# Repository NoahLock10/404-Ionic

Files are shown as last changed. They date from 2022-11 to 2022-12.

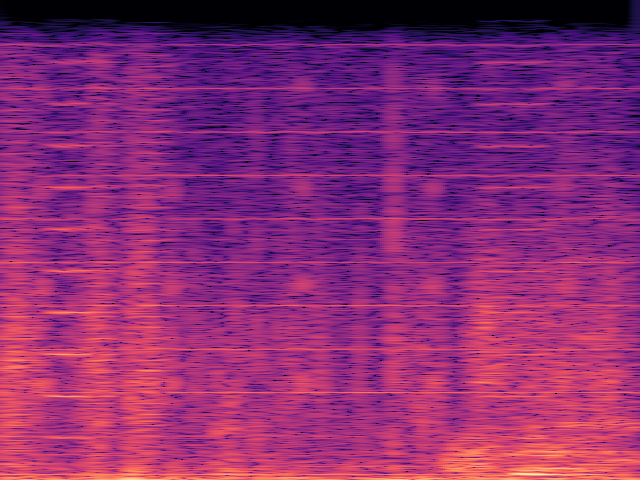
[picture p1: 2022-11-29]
AI_and_Wearable/Pipeline/Scripts/melspec_files/TEST.png

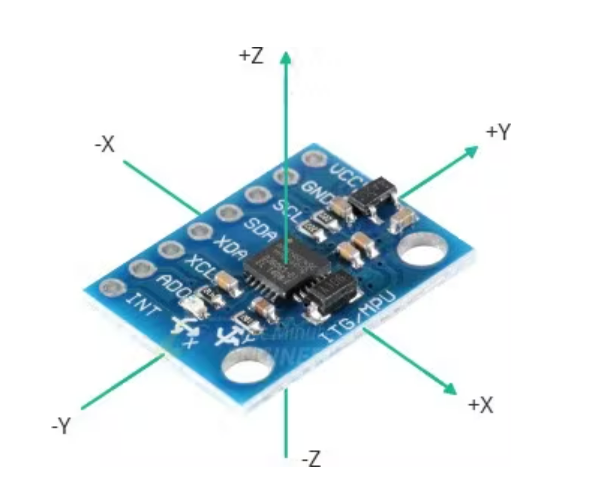
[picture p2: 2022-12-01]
Micro Controller Subsystem/accelrometer axis.png

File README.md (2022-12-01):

# Meltdown_Team-12_Fall_2022

The "src" folder holds the code Noah Lockhart wrote to create the app and connect to the database.
The "android" folder holds the code to allow the app to run on android phones.

The "AI and Wearable" folder holds the code Jason and Josh worked on to record the data on the wearable, 
send the data to the database, and make a meltdown prediction using the AI.

Within the "AI and Wearable" folder, the "Sensors" folder has two subdirectories.
"AI and Wearable/Sensors/Scripts" has all the python scripts used for data collection, as well as the shell script which runs them all together.
"AI and Wearable/Sensors/Data" has all the .txt files that are populated via the data collection scripts.

Within the "AI and Wearable" folder, the "AI" folder contains the model weights for the acoustic CNN and the biometric ANN.

Within the "AI and Wearable" folder, the "Database" folder contains the python script to upload data to the DB via the API.

Within the "AI and Wearable" folder, the "Pipeline" folder contains python modules which provide preprocessing functions and inference functions.
Additionally, this folder contains a main.py file which extracts all data collected during data collection, preprocesses it, and makes a prediction.

Within the "AI and Wearable" folder, the "Final" folder contains the shell script which first calls our data collection script, and then calls
the pipeline script. 

All of the presentations and documents created during 403/404 (CONOPS, FSR, ICD, etc.) can be found in the root directory of the GitHub.
All of the solidwords and altium files and validation files can be found in the root directory of the GitHub.

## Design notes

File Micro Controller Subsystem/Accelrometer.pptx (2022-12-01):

## MPU6050

- Code Flow Chart

Cron-Job
Automated process that runs all scripts on Raspberry Pi 4

Initial Accelerometer Conditions
Setting registers and importing modules

Read_byte(reg)
Reading the address

Read_word(reg)
Reading accelerometer values off MPU6050

Bus Interface
How communication between Pi and MPU6050 is achieved

Data Collection
How Data is collected

Final Output

smbus2
Combine I2C read and write transactions

Return bus.read_byte_data(address, reg)
This is to read a register 0x68 to the circuit

H = bus.read_byte_data(address, reg)
The MPU6060 provides sensor data as unsigned short 16 bit values (-32768 to +32767

Bus = smbus2.SMBus(1)
Interface communication with I2C bus

F = open(“Data/accel.txt”, “w”)
Packet data into txt file

Accel.txt
The final txt file with x, y, and z accelerations

Math/Time
Used for calculations and delays

Address
Lists the addresses of the registers to read a value and the addresses available

L = bus.read_byte_data(address, reg+1)
This data is split across 2 8 bit registers (0-255)

Bus.write_byte_data(address, reg_1, 0)
Write register to the circuit in this case it is a 0

Acceleration_xout = read_word_2c(0x3b)
Utilizes for loops to collet scaled acceleration values from registers

Reg_1 and Reg_2
MPU6050 power management registers (The lists of registers and their address is available in the circuit specification)

Value = read_word(reg)
Reads pair of 8 bit registers

f.write
Writing Data to txt file

If (val>=0x8000)
Converts results to a 16 bit value

## CONTOSO

- Organization chart

Kalle Persson
HR Manager

Flora Berggren
VP Human Resources

April Hansson
Marketing Manager

Mira Karlsson
VP Marketing

Victoria Hanssen
HR Manager

Kalle Persson
Marketing Manager

Angelica Hansson
Product Manager

Mirjam Nilsson
President

Angelica Astrom
Engineering Director

Allan Mattsson
VP Technology

Kalle Persson
VP Product

Victoria Hansson
Product Manager

Jens Martensson
Product Manager

August Bergqvist
VP Finance

Ian Hansson
Accounting Manager

Victoria Persson
VP Transportation

Alexander Martensson
Accounting Manager

## CONTOSO

- Organization chart

Mirjam Nilsson
President

August Bergqvist
VP Finance

Kalle Persson
Accounting Manager

Allan Mattsson
VP Technology

Kalle Persson
Engineering Director

Flora Berggren
VP Operations

Kalle Persson
Facilities Manager

Mira Karlsson
VP Marketing

Kalle Persson
Marketing Manager

Kalle Persson
VP Product

Kalle Persson
Product Manager

Victoria Persson
VP Human Resources

Kalle Persson
HR Manager

Kalle Persson
Accounting Manager

Kalle Persson
Marketing Manager

Kalle Persson
Product Manager

Kalle Persson
HR Manager

Kalle Persson
Accounting Manager

Kalle Persson
HR Manager

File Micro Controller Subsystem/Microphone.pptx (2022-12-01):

## Recorder.py

- Overview of microphone code

Cron-Job
Automated process that runs all scripts on Raspberry Pi 4

Initial Microphone Configurations

Pyaudio.PyAudio()

For loop
Adding chunks of audio to frame array

Stream
Stopping the data collection

Wavfiles
Creating wavfile from recorded audio with microphone requirments

Environment.wav
Final output file

Form_1 = pyaudio.paInt16
Initializing a 16-bit resolution

Audio = pyaudio.PyAudio()
Creating an instantiation of pyaudio

Frames.append(data)
Adding the parsed data to new frame array

Stream.stop
Stop stream

Wave.open
Open create and write

Verification
Matlab code in appendix A verifies data using spectrograph

Chans =1
1 channel being created

Stream = audio.open()
Creating a stream that can later be parsed

Samp_rate/chunk *record_secs
How many iterations of collection

Stream.close
Close the stream

Wave.setnchannels
Only create 1 channel

samp_rate = 44100
Chunk = 4096
Collecting audio at 44.1 kHz with 4096 samples

Print(“recording”)
Visible proof that there is audio being recorded

Audio.terminate
Stop recording

Wave.setsamplewidth
Set wavfile sample rate to 44100 HZ

Record_specs = 3
dev_index = 2
Recording audio for 3 seconds and setting which USB port is being used

Format of audio.open
Default settings for microusb microphone

Wavefile.writeframes
Combining all created frames

## CONTOSO

- Organization chart

Kalle Persson
HR Manager

Flora Berggren
VP Human Resources

April Hansson
Marketing Manager

Mira Karlsson
VP Marketing

Victoria Hanssen
HR Manager

Kalle Persson
Marketing Manager

Angelica Hansson
Product Manager

Mirjam Nilsson
President

Angelica Astrom
Engineering Director

Allan Mattsson
VP Technology

Kalle Persson
VP Product

Victoria Hansson
Product Manager

Jens Martensson
Product Manager

August Bergqvist
VP Finance

Ian Hansson
Accounting Manager

Victoria Persson
VP Transportation

Alexander Martensson
Accounting Manager

## CONTOSO

- Organization chart

Mirjam Nilsson
President

August Bergqvist
VP Finance

Kalle Persson
Accounting Manager

Allan Mattsson
VP Technology

Kalle Persson
Engineering Director

Flora Berggren
VP Operations

Kalle Persson
Facilities Manager

Mira Karlsson
VP Marketing

Kalle Persson
Marketing Manager

Kalle Persson
VP Product

Kalle Persson
Product Manager

Victoria Persson
VP Human Resources

Kalle Persson
HR Manager

Kalle Persson
Accounting Manager

Kalle Persson
Marketing Manager

Kalle Persson
Product Manager

Kalle Persson
HR Manager

Kalle Persson
Accounting Manager

Kalle Persson
HR Manager

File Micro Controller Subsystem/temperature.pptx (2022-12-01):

## Temperature Sensor

- Code Flow Chart

Cron-Job
Automated process that runs all scripts on Raspberry Pi 4

Initial Imports
Import modules necessary for data collection

Def read_temp_raw()
Reading data into file with non converted data

Def read_temp()
Stripping the data so each individual value can be converted to Fahrenheit through a while loop

Conversion
Raw data to Fahrenheit

Data Collection
10 values produced in 30 seconds

Final Output

Import os
Used to read from Pi and temperature sensor

Device_folder = glob.glob(base_dir +’28’)
Default location of sensor in PI

While lines[0].string()[-3:]
While loop checking if there's data

Temp_f = temp_c * 9 /5 +32
Numerical conversion

f.write(curr_temp +’\n’)
Writing new data to final output

Temp.txt
When final temperature values go

Import glob
Finds all pathnames matching a specified pattern

Device_file = device_folder + ‘/w1_slave’
Default location of sensor data in pi

Lines = read_temp_raw()
Getting values using loops

Import glob
Finds all pathnames matching a specified pattern

Lines = f.readlines()
Reading file data line by line

Return lines
Returning the data so future functions can use it

## CONTOSO

- Organization chart

Kalle Persson
HR Manager

Flora Berggren
VP Human Resources

April Hansson
Marketing Manager

Mira Karlsson
VP Marketing

Victoria Hanssen
HR Manager

Kalle Persson
Marketing Manager

Angelica Hansson
Product Manager

Mirjam Nilsson
President

Angelica Astrom
Engineering Director

Allan Mattsson
VP Technology

Kalle Persson
VP Product

Victoria Hansson
Product Manager

Jens Martensson
Product Manager

August Bergqvist
VP Finance

Ian Hansson
Accounting Manager

Victoria Persson
VP Transportation

Alexander Martensson
Accounting Manager

## CONTOSO

- Organization chart

Mirjam Nilsson
President

August Bergqvist
VP Finance

Kalle Persson
Accounting Manager

Allan Mattsson
VP Technology

Kalle Persson
Engineering Director

Flora Berggren
VP Operations

Kalle Persson
Facilities Manager

Mira Karlsson
VP Marketing

Kalle Persson
Marketing Manager

Kalle Persson
VP Product

Kalle Persson
Product Manager

Victoria Persson
VP Human Resources

Kalle Persson
HR Manager

Kalle Persson
Accounting Manager

Kalle Persson
Marketing Manager

Kalle Persson
Product Manager

Kalle Persson
HR Manager

Kalle Persson
Accounting Manager

Kalle Persson
HR Manager

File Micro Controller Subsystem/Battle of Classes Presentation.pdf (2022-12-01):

Gavin Marquez: (Leader) Hardware and Sensors Lead

Alexander Duvall: (Assistant Leader) Software and Firmware Lead

Allen Torres: (Resource Manager) System and Automation Lead

Joel Martinez: (Scribe) Communication and Networking Protocol Lead

Saif Momin: (Reflector) Modeling and Prototyping Lead

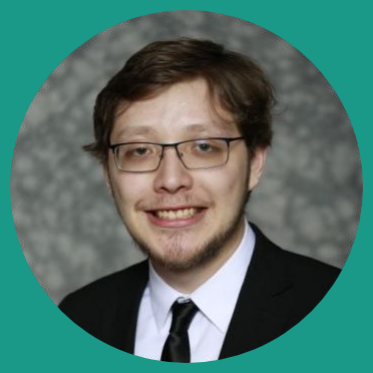
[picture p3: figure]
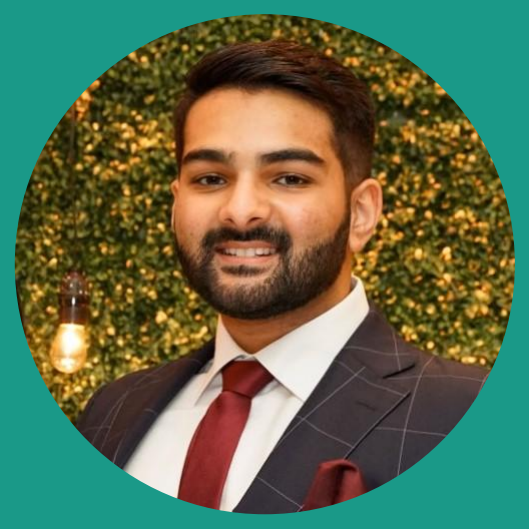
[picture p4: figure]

# Project MARKUS: Ai Driven Solutions

# What is ASD?

Autism Spectrum Disorder, a developmental disability that causes serious social, behavioral and communication challenges.

- Diagnosis for Autism Spectrum Disorder (ASD) encompasses:
- Autistic Disorder; Pervasive Developmental Disorder (PDD-NOS); Asperger Syndrome
- Signs and Symptoms:
- Social, Emotional, and Communication problems
- Behavioral Therapy used to treat ASD
- Helps in cognitive and social development.
- Helps develop daily living skills
- Assists individuals communicating with the Community
- Each individual is different and requires different forms of therapy
- Behavioral therapy is commonly used with children
- Not many people treat ASD in adults or teens.

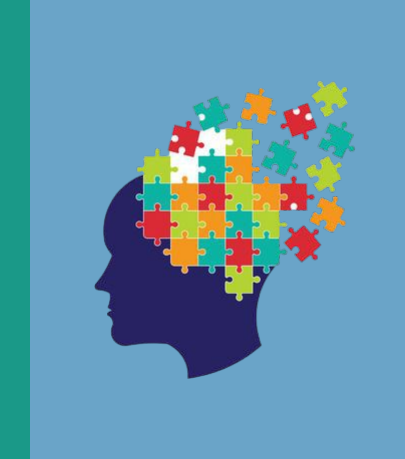
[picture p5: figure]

“Findings estimate autism affects 1 in 45, or 2.21 percent, of U.S. adults.” - AutismSpeaks | [1,2,5]

# Common Occurrences with ASD

Each person with ASD is different, but through
interviews, we have been able to narrow down some common trends through interviews and research:
- Sensory Overloads
- Sounds, loud or high pitched.
- Fluorescent lights
- Such sensations can be painful
- Strong smells as triggers
- Discomfort in clothing
- Loss in routines may cause problems
- Lack of micro-expressions
- Indicator of someone on the spectrum

Upon a disturbing noise, an individual with ASD may cover their ears to limit pain.

Information gathered in conjunction with Jennifer Morgan, Sofia Lumbo, and Marianne [1,2,6]

# What are meltdowns?

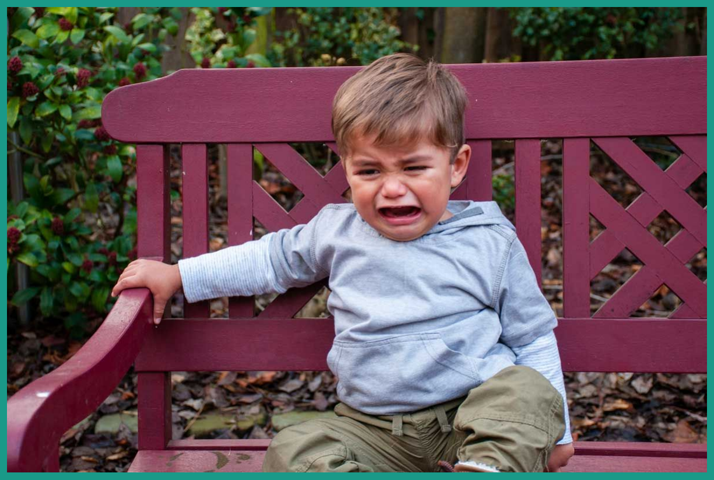
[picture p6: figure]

- Meltdowns : is an intense response to overwhelming circumstances—a complete loss of behavioral control.
- Causes of Meltdown: Sensory Overload, Information Overload, Emotional Overload
- Examples: Physical Sign of Anxiety, Need to leave the environment, or physical harm towards oneself

Information gathered in conjunction with Jennifer Morgan, Sofia Lumbo, and Marianne [3,4]

## What can we do?

- Preventive Measure for Meltdown.
- Deescalate the situation
- Interruption and Transitions
- Practice Routine and practice change in routine
- Provide Safe Space
- Redirect their attention elsewhere.
- Early Intervention is key to saving lives

# What are meltdowns?

# Meet Markus

Markus is a Wearable device that will watch and monitor the wearer and their environment.

- Artificial Intelligence
- Monitor for Noise, stimuli
- Microphone
- Stress levels
- Heart Rate
- Location
- Temperature
- Environmental Attributes
- Camera

While the belt is on, Markus will be able to utilize Ai to ensure the user is well.
With this technology, Markus will be able to prevent or deescalate meltdowns, help find a missing person, and speak to them. Information gathered in conjunction with Jennifer Morgan,Sofia Lumbo and Marianne

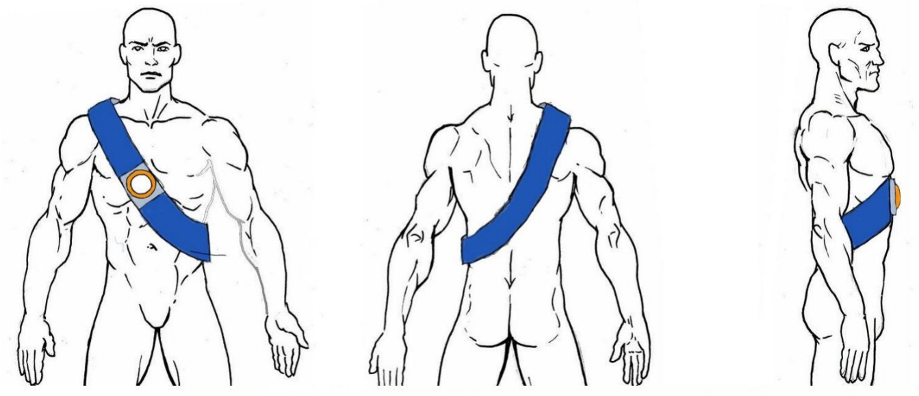
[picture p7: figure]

While the belt is on, Markus will be able to utilize Ai to ensure the user is well.
With this technology, Markus will be able to prevent or deescalate meltdowns, help find a missing person, and speak to them. Information gathered in conjunction with Jennifer Morgan,Sofia Lumbo and Marianne

# Markus AI Model

The brain of Markus will be using a custom built deep learning model. The Ai will be able to understand environmental sounds and determine if a meltdown is imminent with information from other sensors.

### Training

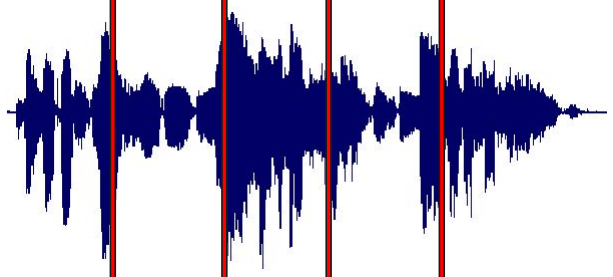
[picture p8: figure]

Audio Samples were recorded from a variety of environments like:
- Malls
- Retail stores
- Restaurants
- Festivals
- Public Areas

Audio Samples were then split up to 1.5 seconds each and used for training.

Every 1.5 seconds, Markus interprets the environment’s sounds into 6 categories
- Quiet, Small Conversation, Large conversation, Stimuli Wind, noise

# Markus Artificial Intelligence

# Markus Artificial Intelligence

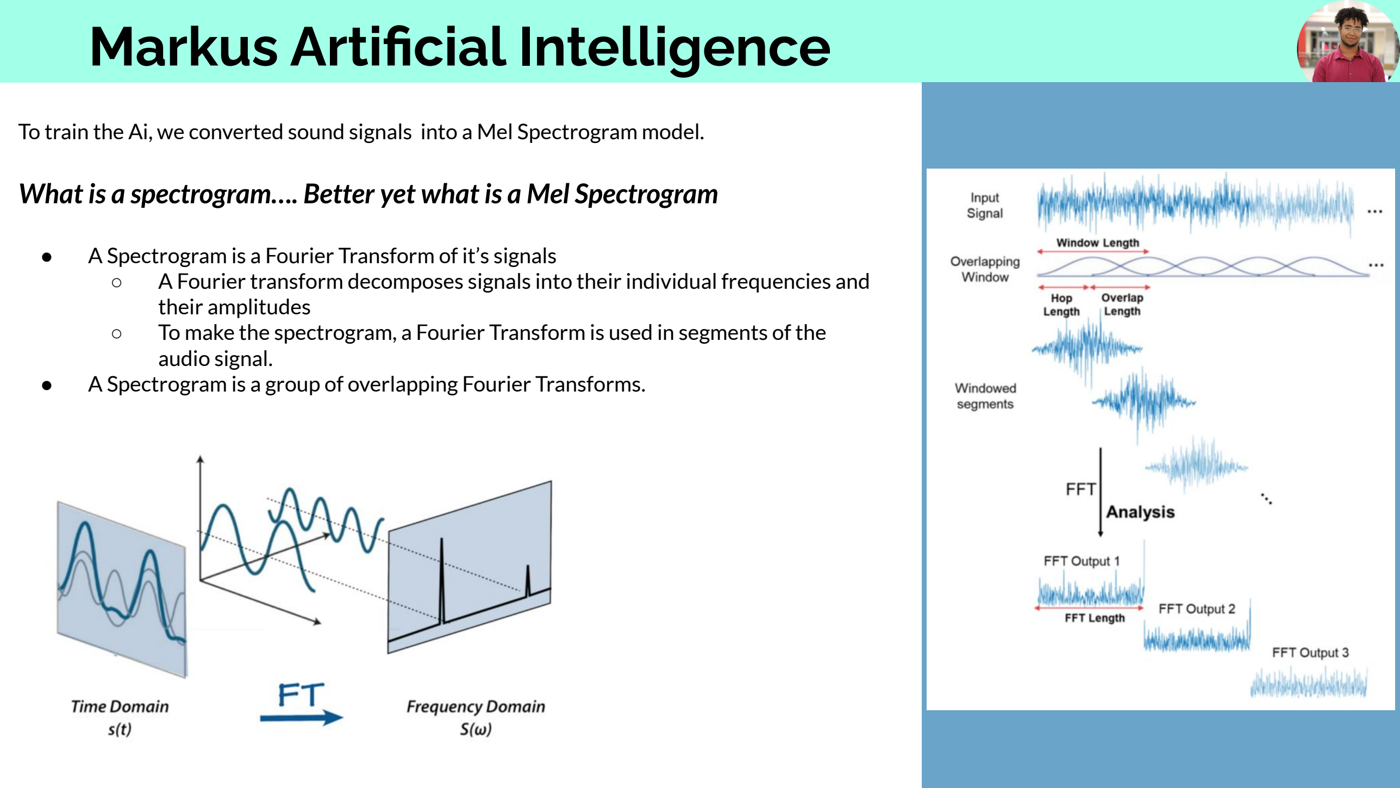
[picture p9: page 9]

To train the Ai, we converted sound signals into a Mel Spectrogram model.

What is a spectrogram…. Better yet what is a Mel Spectrogram

- A Spectrogram is a Fourier Transform of it’s signals
- A Fourier transform decomposes signals into their individual frequencies and their amplitudes
- To make the spectrogram, a Fourier Transform is used in segments of the audio signal.
- A Spectrogram is a group of overlapping Fourier Transforms.

# Markus Artificial Intelligence

Okay, what about a Mel Spectrogram?

- A Mel Spectrogram is a spectrogram converted to how human’s interpret sound
- Humans can tell the difference between a 500 and 1000 Hz sound
- However, we can not tell the difference between a 10,000 and 15,000 Hz Sound
- Depending on the frequency of the sound, it is given a pitch value that is equivalent to how we interpret sound.
- This interpretation is then calculated into a new spectrogram

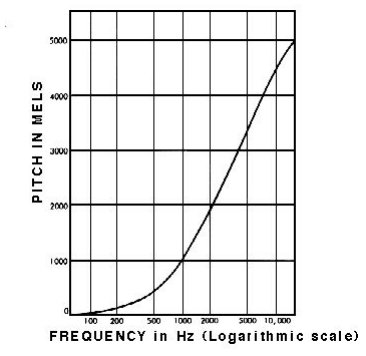
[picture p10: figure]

# Markus Artificial Intelligence

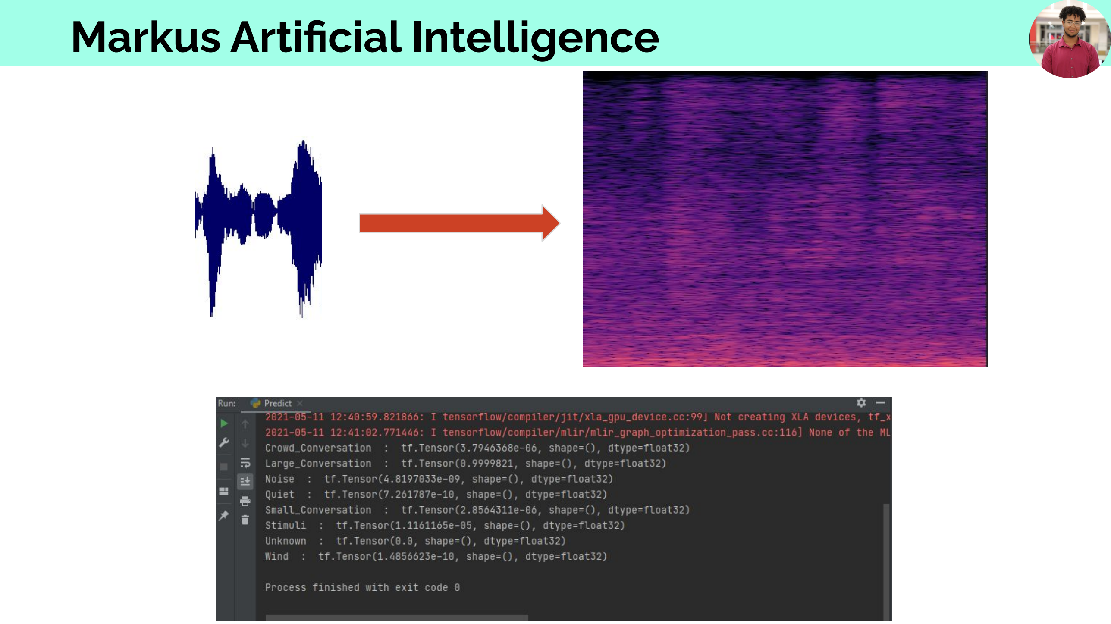
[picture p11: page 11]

# Markus Artificial Intelligence Performance

# Markus Artificial Intelligence Performance

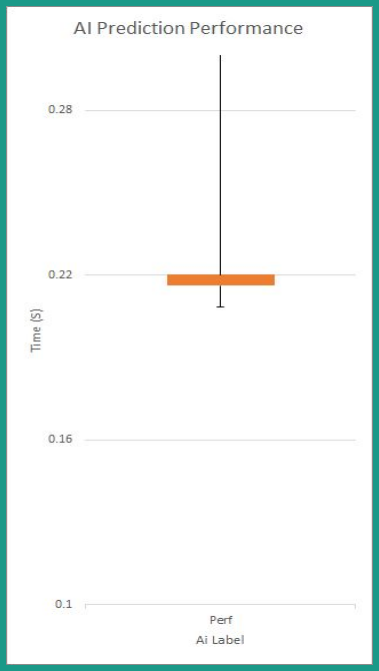
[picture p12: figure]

# GPS Sensor Performance

# Heart Beat Sensor Performance

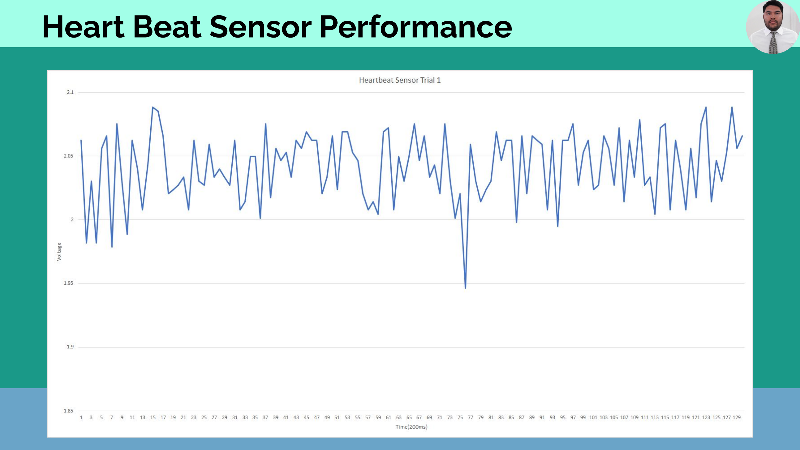
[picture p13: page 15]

# Heart Beat Sensor Performance

# Heart Beat Sensor Performance

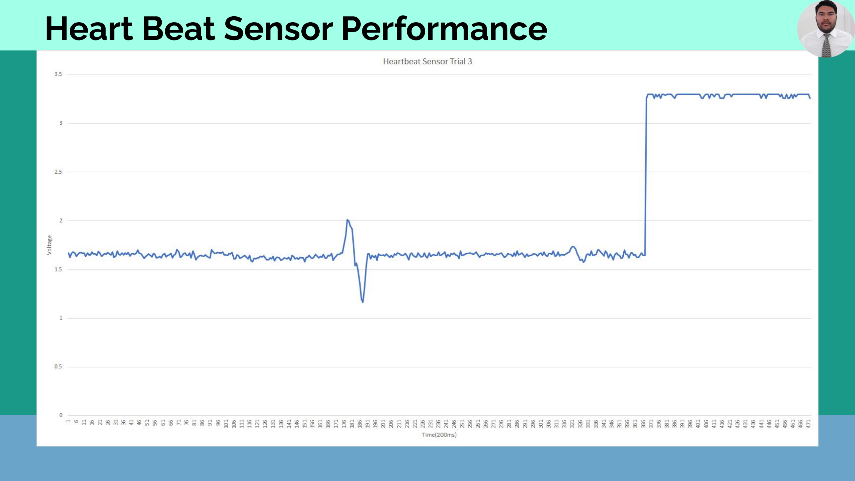
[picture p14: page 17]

# Putting it all together - Servers

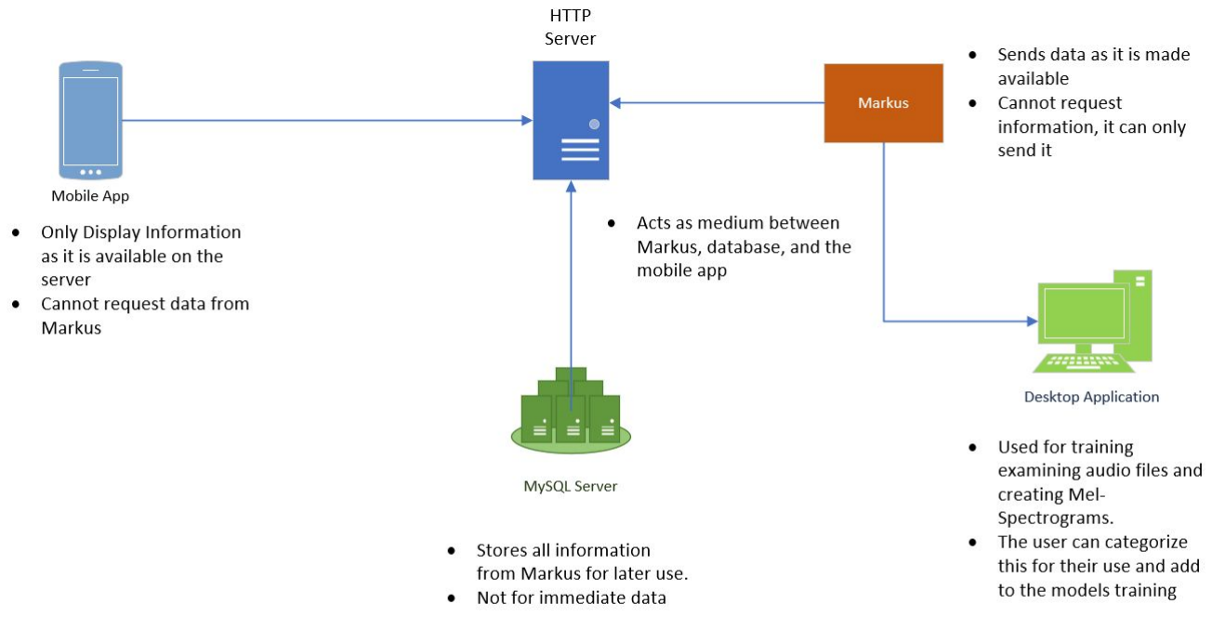
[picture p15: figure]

# Putting it all together - Servers

React Native and Expo.IO

-React Native allows for the Combination of JavaScript, CSS, and HTML all combined into one to create native mobile application for both IOS and Android Devices

-Expo.io an online IDE used to build React Native application and test with in real time. Expo.io allows for the application to be loaded onto a mobile device for live testing as well

# Tools to create the Mobile Application

With the mobile app, a guardian or caretaker can directly monitor their individuals status and environment. Everything Markus can see and hear is sent directly to the phone

- With an Embedded Camera and Microphone Markus can live
stream video and calls.
- Markus’ location, pressure, altitude, and humidity are directly sent
to the app.
- The ai’s interpretation of the environment is also sent to the app.

All information is updated as it is made available

# Mobile Application

# Mobile Application (2)

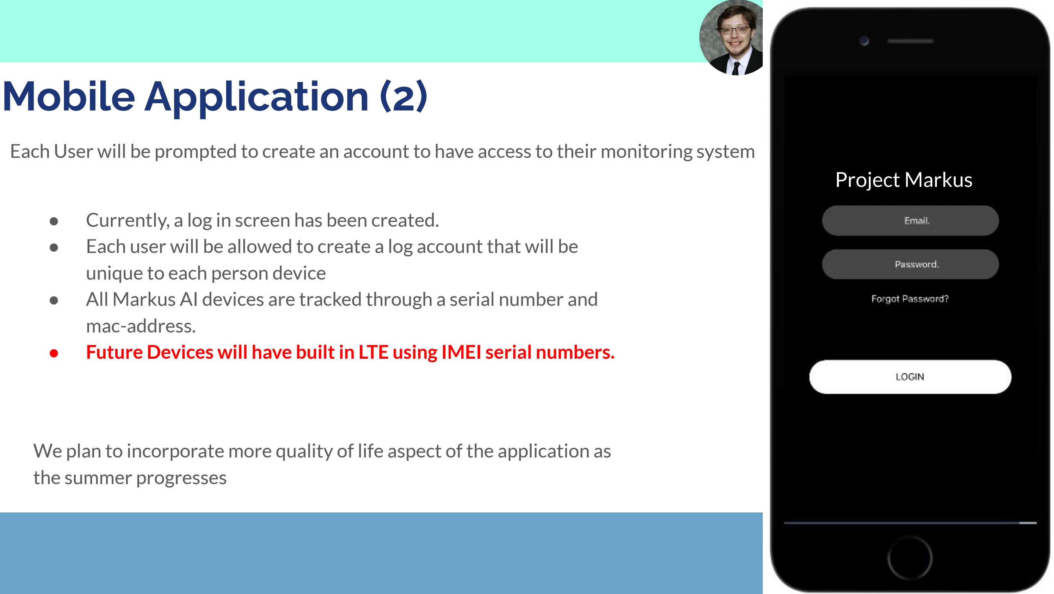
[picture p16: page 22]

Each User will be prompted to create an account to have access to their monitoring system

- Currently, a log in screen has been created.
- Each user will be allowed to create a log account that will be
unique to each person device
- All Markus AI devices are tracked through a serial number and mac-address.
- Future Devices will have built in LTE using IMEI serial numbers.

We plan to incorporate more quality of life aspect of the application as the summer progresses

Project Markus

# NVIDIA Jetson Nano - The Brain

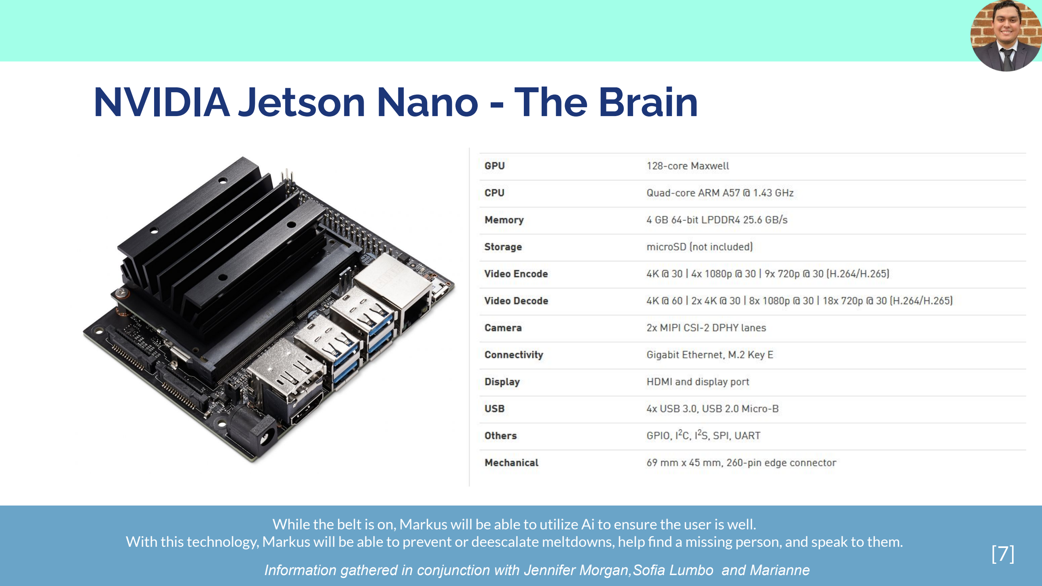
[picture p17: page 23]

While the belt is on, Markus will be able to utilize Ai to ensure the user is well.
With this technology, Markus will be able to prevent or deescalate meltdowns, help find a missing person, and speak to them.

Information gathered in conjunction with Jennifer Morgan,Sofia Lumbo and Marianne

Nvidia’s Jetson Nano is an embedded system that allows multiple neural networks to run in parallel. These neural networks can be used for:

- Image Classification
- Object Detection
- Segmentation
- Speech Processing

This device runs on 5 watts, and it is able to train and deploy AI software.

[7]

BME280: Environmental sensor that measures Temperature, Humidity, Pressure, and Altitude

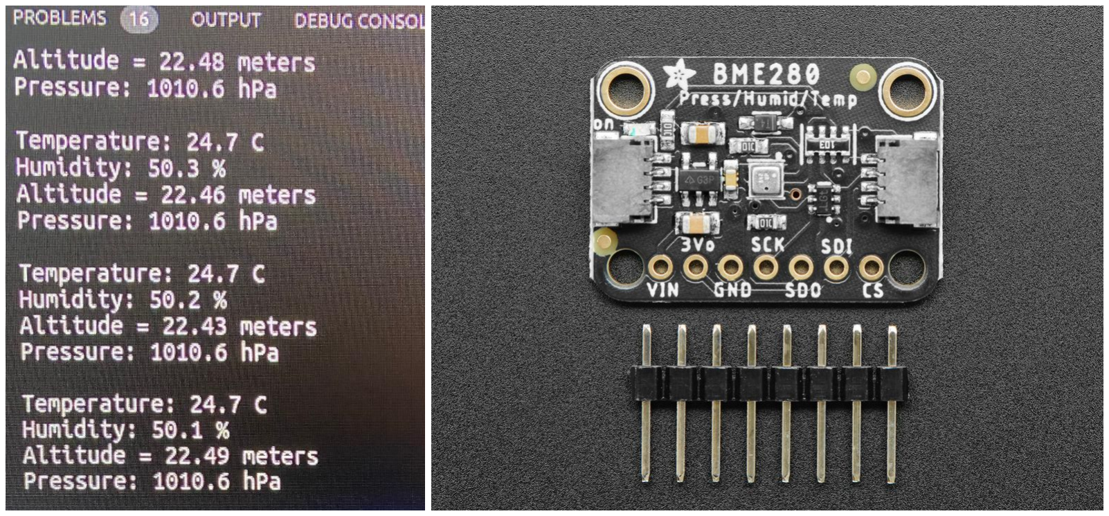
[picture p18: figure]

- Can be wired using I2C or SPI
- Temperature accuracy with ∓ 1.0C
- Humidity accuracy with ∓ 3%
- Pressure accuracy with ∓ 1 Hpa
- Altitude accuracy with ∓ 1 meter ●

# Temperature Sensor

Ultimate GPS Breakout V3: High quality GPS module that can track up to 22 satellites on 66 channels.

- Uses UART terminal
- Uses 3.3 - 5V
- Can connect any 3V active GPS antenna for better accuracy ●

# GPS Sensor

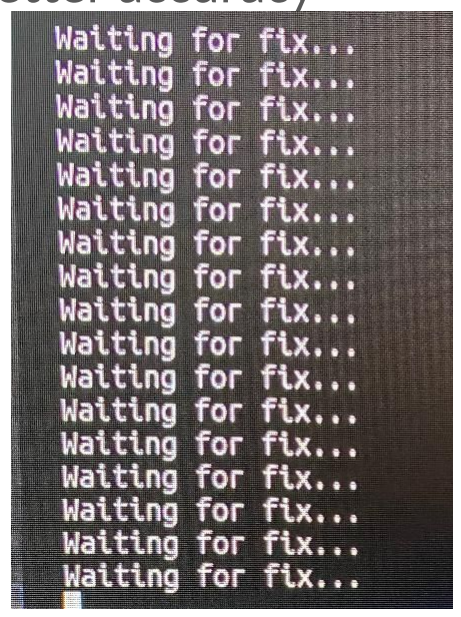
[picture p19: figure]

Pulse Sensor: uses Photoplethysmography (PPG) to determine heart rate. PPG accuracy are heavily affected by measurement procedure and environmental factors.

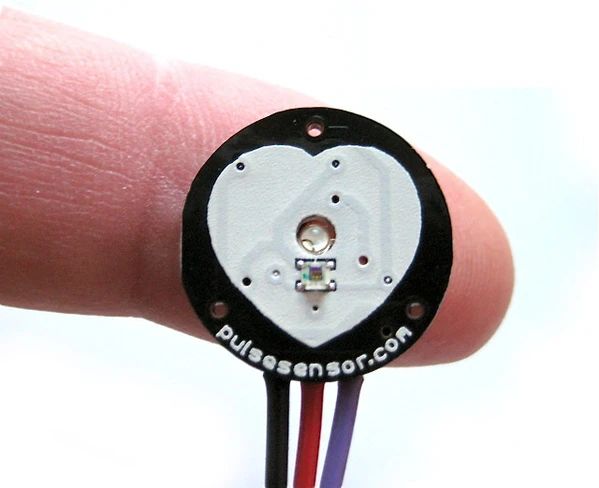
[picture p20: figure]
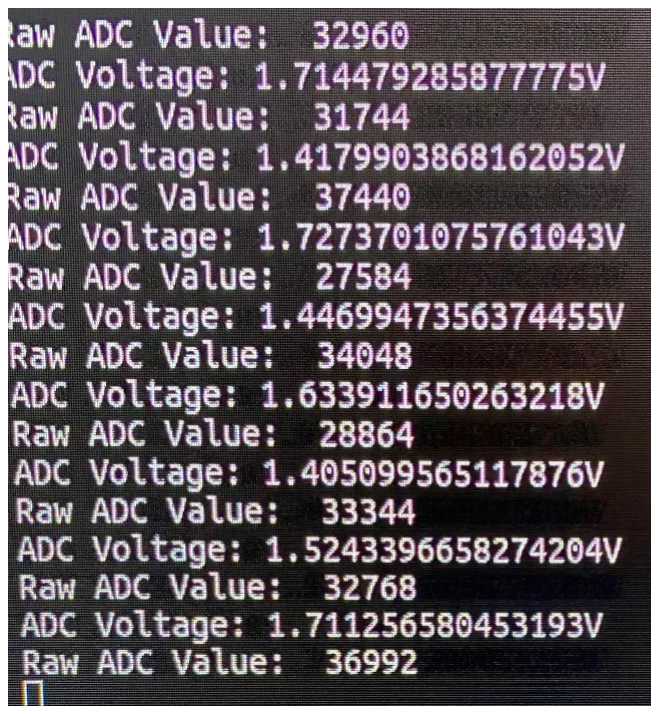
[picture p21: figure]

- Analog Signal
- Uses 3 - 5V
- Can be worn around finger, or earlobe

# Heart Rate Sensor

Raspberry Pi Module V2:

- Small Compact Size
- Resolution up to 1080p at 30 fps
- Still resolution of 8 Megapixels
- Horizontal Field of View of 62 degrees

# Camera

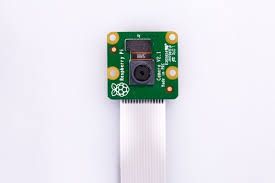
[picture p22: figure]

# Microphone and Speaker

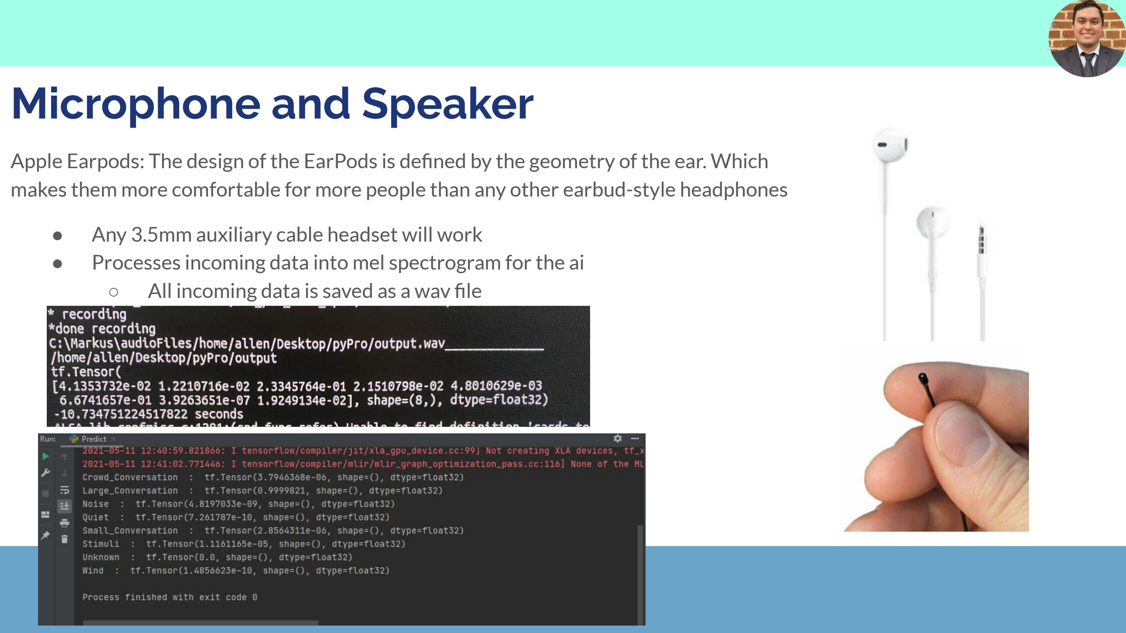
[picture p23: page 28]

Apple Earpods: The design of the EarPods is defined by the geometry of the ear. Which makes them more comfortable for more people than any other earbud-style headphones

- Any 3.5mm auxiliary cable headset will work
- Processes incoming data into mel spectrogram for the ai
- All incoming data is saved as a wav file

# Demo

3D Model of MARKUS Enclosure

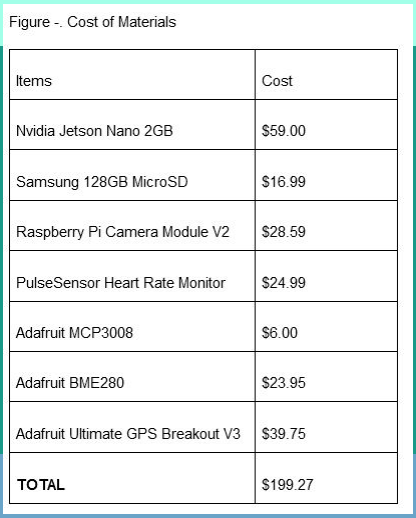
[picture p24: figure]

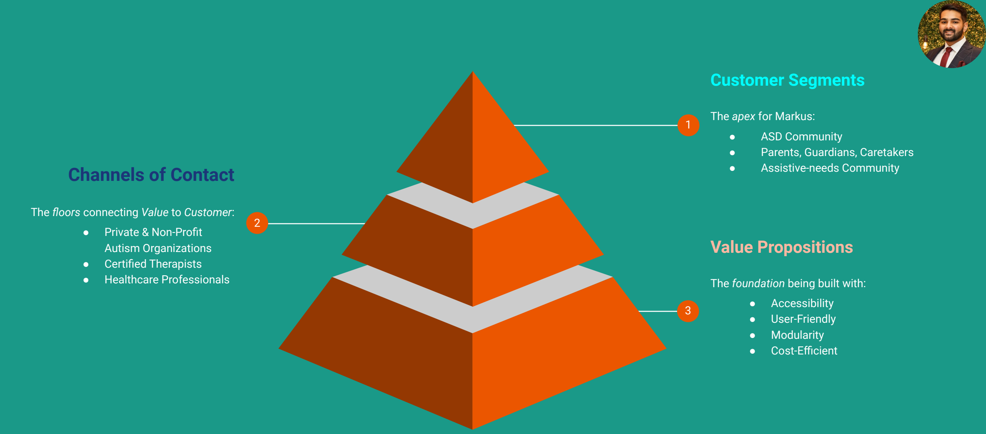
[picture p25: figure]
Value Propositions; The foundation being built with:; ● Accessibility ● User-Friendly ● Modularity ● Cost-Efficient; Channels of Contact; ● Private & Non-Profit Autism Organizations ● Certified Therapists ● Healthcare Professionals; Customer Segments; The apex for Markus:; ● ASD Community ● Parents, Guardians, Caretakers ● Assistive-needs Community

The floors connecting Value to Customer:

# MARKUS: It’s Business

# So what… Why should we care?

Markus is meant to replace human interaction when it is not possible for someone to be there.

### - Preventing meltdowns from occurring - Assisting in the de-escalation of meltdowns - Finding lost individuals that wonder from supervised areas (AKA wondering)

- Learning when a meltdown is going to take place for each individual.

### - Introduce new and familiar grounding exercises

- Early Stage Intervention, when no one is there to intervene.

We hope Markus will become a common assistant that can help those with ASD cope with unpredictable situations and a thing called life.

# Project Shortcomings and Problems

- Mel Spectrogram performance is slow.
- Ai may be biased.
- Server is unable to stream microphone and camera data.
- Pulse Sensor cannot be fit correctly for accurate data
- No Data exists in relation to autism and meltdowns.

# What’s Next?

Work to finetune our proof of concept and prototyping.
Working with Treatment centers all over the US and around the world to research, gather info, and improve Markus AI on ASD individuals.
We will build an online presence using our social media platforms such as:
1. Facebook (Groups such as family with ASD, posting and advertising, Instagram videos/posts)
2. Google (SEO, Youtube Videos)
3. Twitter (Videos)
4. Feature our products on Forbes/Tech Magazines/Startups/etc
5. Crowd Funding: Startups/Indiegogo/etc
6. Website presence and product info
7. Forums: Participate in forums and discussions website Fundings (could be in any order):
Venture capitalists
Angel investors
Crowdfunding
Equity crowdfunding
Incubators
Grants
Friends and Family

The Bauer College of Business’s Red Labs has selected us to continue with our project. This is a great opportunity for us because it will allow us to:

- Gather necessary knowledge in order to create start up
- Network with professionals.
- Keep developing our device.
- Present prototype to industry professionals and companies.

The opportunity offered by Red Labs is a big step into one day making our device available to people with special needs.

# UH Red Labs

# References

[1] What is Autism Spectrum Disorder?, 25-Mar-2020. [Online]. Available: https://www.cdc.gov/ncbddd/autism/facts.html. [Accessed: 19-Nov-2020].
[2] “CDC estimates 2.2 percent of adults in U.S. have autism,” Autism Speaks, 13-May-2020. [Online]. Available: https://www.autismspeaks.org/science-news/cdc-estimates-22-percent-adults-us-have-autism. [Accessed: 19-Nov-2020].
[3] “Meltdown,” Merriam-Webster. [Online]. Available: https://www.merriam-webster.com/dictionary/meltdown. [Accessed: 19-Nov-2020].
[4] “Keeping Your Child with Autism Safe,” The Autism Community in Action (TACA), 19-Oct-2020. [Online]. Available: https://tacanow.org/family-resources/keeping-your-kids-with-asd-safe/. [Accessed: 19-Nov-2020].
[5]Centers for Disease Control and Prevention. 2020. Treatment | Autism Spectrum Disorder (ASD) | NCBDDD | CDC. [online]
Available at: <https://www.cdc.gov/ncbddd/autism/treatment.html> [Accessed 30 November 2020].
[6] Healthline. 2020. Sensory Overload: Symptoms, Causes, Related Conditions, And More. [online] Available at: <https://www.healthline.com/health/sensory-overload#causes> [Accessed 30 November 2020].
[7]“Jetson Nano Developer Kit,” NVIDIA Developer, 09-Oct-2020. [Online]. Available: https://developer.nvidia.com/embedded/jetson-nano-developer-kit. [Accessed: 15-Dec-2020].

Gavin Marquez: (Leader) Hardware and Sensors Lead

Alexander Duvall: (Assistant Leader) Software and Firmware Lead

Allen Torres: (Resource Manager) System and Automation Lead

Joel Martinez: (Scribe) Communication and Networking Protocol Lead

Saif Momin: (Reflector) Modeling and Prototyping Lead

# Supplementary Slides

# THANK

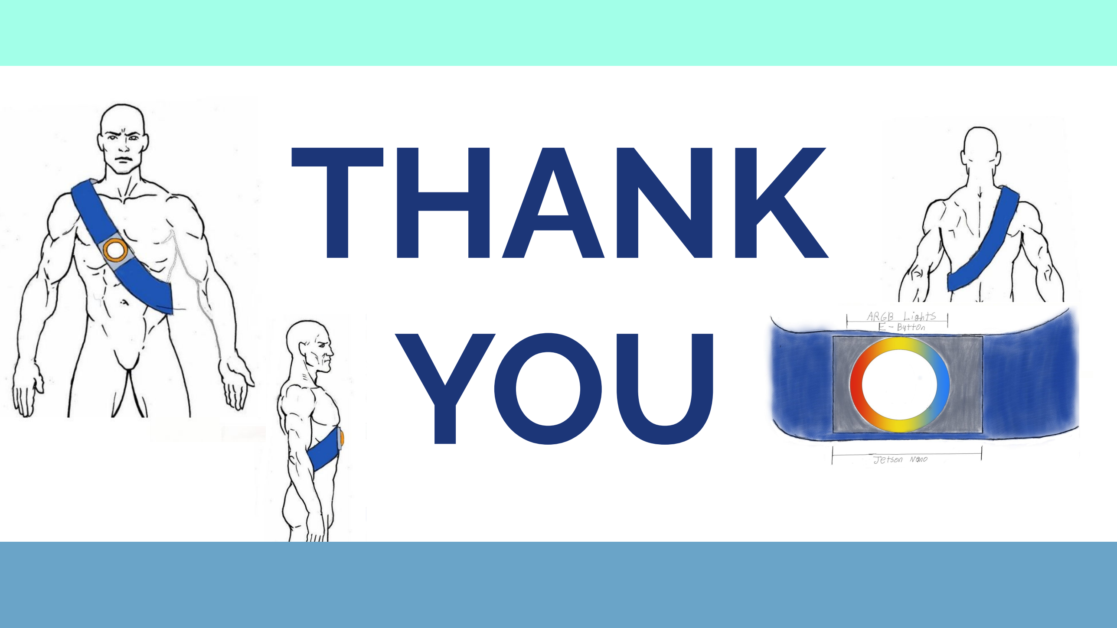
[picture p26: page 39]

# YOU

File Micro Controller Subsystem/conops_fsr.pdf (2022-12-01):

# Mitigating Autistic Meltdowns

## Joshua Kao, Jason Kroslowitz, Noah Lockhart, Andres Perez

# Concept of Operations

### REVISION – Draft

### 06 February 2022

Concept Of Operations | Revision 1
Mitigating Autistic Meltdowns

## Concept of Operations

## for

# Mitigating Autism Meltdowns

Team 12

Approved by:

__Team 12___________________2/08/22__

Project Leader | Date

___________________________________

Prof. Kalafatis | Date

___________________________________

T/A | Date

### Change Record

Rev. | Date | Originator | Approvals | Description
-1 | [2/08/2022] | [Team 12] | | Draft Release

### Table of Contents

### List of Figures

# 1. Executive Summary

An autistic meltdown is an involuntary coping mechanism to excessive stimuli, and can be associated with intense and explosive behaviors. These events pose a threat to the safety of these individuals and in some cases others around them. Rather than having a caretaker supervise them 24/7, we propose a device that mitigates meltdowns for these individuals. The 12th Man is a hip wearable device that mitigates meltdowns for individuals with Autism. By monitoring the user's biometrics, the 12th Man uses artificial intelligence to process these signals and predict if a meltdown is imminent. If a meltdown is imminent, an alert is sent to the subject's parent(s) or guardian through an app with the location of the individual and the probability that a meltdown is going to happen. On the device itself a recording from a loved one is played with grounding exercises to calm down the individual. We are hoping that through this device, the lifestyles of autistic people can be changed.

# 2. Introduction

The following is an introduction to The 12th Man, a device capable of monitoring, mitigating, and supporting individuals with autism no matter where they are. The 12th Man will provide a sense of comfort for these individuals and their loved ones through its prediction, mitigations, and location tracking of meltdowns.

## 2.1. Background

Autism spectrum disorder (or ASD for short) is a disorder that affects social, emotional, and communication skills. Although the cause is still unknown, it is believed to develop from a combination of genetic, nongenetic, and environmental influences. Recently, ASD has been more heavily researched, and as a result, more conditions have been connected to the disorder. Although symptoms differ per individual, some common symptoms include anxiety, ADHD, epilepsy, schizophrenia, and others.

It is also common for individuals with ASD to be easily agitated. Due to this, meltdowns are an ailment that affect many autstic people. A meltdown is a result of stressors that cause an overload for the individual. During a meltdown, “involuntary physical and emotional reaction to a situation” can occur. While meltdowns can happen with any individual, people with ASD are more prone to them due to the inability to process the overload of stimulants from the surrounding environment. Some examples of these extraneous stressors could be any variety of loud noises, large crowds, and sometimes just everyday life. Meltdowns can result in devastating effects such as wandering, self harm, harm to others, and in the worst case scenarios death.

Typically when addressing meltdowns, it is best to try to prevent them from even happening. Family and friends are the best suited for this task since these individuals understand when there could be potential stressors to the person expecting a meltdown. They are also the most equipped to develop grounding exercises which can help calm the person down. Grounding exercises are a series of activities, patterns, or words that help calm an autistic person down. The tell tale signs are different for each person who experiences a meltdown, so it is important to tailor an individual grounding plan for each person. Currently the method of preventing a meltdown is having the parent/guardian around to assist with the grounding exercises. The other current option is to leave the individual unsupervised.

While having family and friend supervision is ideal, we all know that it is not feasible 24/7. This is where the 12th Man comes to action to predict, prevent, and calm-down meltdowns through artificial intelligence and biometrics.

## 2.2. Overview

The 12th Man device will be a wearable device on the hip that will collect biometric and environmental data such as position, body temperature, heart rate, acceleration, and environmental audio. The devices inside the wearable include a gps module, sensors, and a microphone to collect data. The microcontroller will be supplied power by a rechargeable battery. Data received from the sensors will be filtered and sent to a cloud to be stored and classified. It will then be stored in a database, and will be readily available for the mobile application to fetch and display. If the artificial intelligence infers a meltdown is likely, the mobile application will receive a notification of a possible meltdown. Furthermore, an audio recording of a loved one will be outputted through a speaker on the wearable to aid in the mitigation process. Grounding exercise instructions will be included in the audio to calm the user. Finally, the location of the individual will be tracked in the case of the individual wandering which could lead to dangerous outcomes.

## 2.3. Referenced Documents and Standards

- G., T., Brandon W. | 8 years old, Warren W. | 17 years old, & Andrew S. | 17 years old.
(n.d.). Autism speaks. Autism Speaks. Retrieved February 8, 2022, from https://www.autismspeaks.org/
- How many people are diagnosed with autism in the U.S. Therapeutic Pathways. (2021, February 27). Retrieved February 8, 2022, from https://www.tpathways.org/faqs/how-many-people-have-autism/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,sp ectrum%20disorder%20%E2%80%93%20over%2075%2C000%2C000%20people.

# 3. Operating Concept

## 3.1. Scope

The 12th Man mitigation system for autistic meltdowns is a wearable device composed of a microcontroller and sensors. The system will monitor the biometrics of the wearer and collect data from the individual’s environment. Using artificial intelligence, we will identify the precursors of a meltdown in individuals with autism, and make a prediction about whether a meltdown is likely to occur. If a meltdown is likely to occur, a recording from a loved one will be played through speakers on the wearable. The wearable will also store the data it collects in a remote database. This database will be accessible by a mobile application, which will provide parents/guardians with information regarding the location and meltdown status of their dependent.

## 3.2. Operational Description and Constraints

The 12th Man is a noninvasive, wearable device that operates without any work from the individual. It is intended to be used by the ASD community and their loved ones. While wearing the device, biometric and environmental data will be collected continuously. The wearer will only interact with The 12th Man if an event occurs. Speakers will begin to play audio of their loved ones walking them through a grounding exercise. While using the app, parents/guardians will be able to receive continuous biometric data, location data, and notifications of an imminent meltdown. In order for The 12th Man to perform properly, all the following criteria must be met.

1. The user is wearing the charged 12th Man device.
2. The user is wearing the heart rate monitor around their chest.
3. Parents/Guardians will have to have The 12th Man app installed on their phone and linked to the device.
4. The device wearer must have cellular or internet connection.
5. Past 5 hours the device will lose power causing the user to be unmonitored.

Additionally The 12th Man is not waterproof or perfect. There is a risk of a damaged sensor sending the wrong biometric data to the app which could potentially cause a fake alert.

## 3.3. System Description


Figure 1: The 12th Man Block Diagram

The 12th Man will be composed of four subsystems. These include artificial intelligence, power supply, mobile application, and interfacing sensors with cleaning data.

Interfacing Sensors: The 12th Man device includes 5 different sensors: GPS, temperature, accelerometer, pulse, and audio. Each sensor will be wired to a Raspberry Pi microcontroller. The sensors will collect and “clean” or filter out the noise from the data through a combination of hardware (filters and op amps) along with some software. The data will then be assembled into packets and sent to the cloud.

Power Supply: The wearable device will have a rechargeable battery in place that will be composed of a battery in a battery holder. The battery will be connected to a battery management system for fuel gauge and a charging port. The batteries will be lithium-ion polymer batteries so they will be able to be recharged. The battery will be recharged by an AC/DC adapter. The rechargeable battery will be connected as an input to a boost converter in order to step up the voltage to meet the required specifications to power the microcontroller as the output of the boost converter will be connected to a stripped end of a usb-c cable that will have the usb-c end supply power to the microcontroller. This amp-hour specification of the battery will help make battery life last.

Artificial Intelligence: The AI subsystem has several parts. A supervised learning algorithm has been developed by our sponsor to do classification on audio samples. Data preprocessing will entail converting audio samples to mel spectrograms. A CNN will then classify the likelihood of the audio sample originating from one of six types of environments (small conversation, stimuli, large conversation, etc). Another classification model will be constructed, taking as inputs some/all of the biometrics and the output of the acoustic classifier. This model is the final step in the pipeline to predict a meltdown. Should the environment be deemed stressful or over-stimulative, and the vitals indicative of physiological stress, the model will predict a meltdown is likely to occur. Lastly, we may consider building an additional artificial intelligence based on a generative adversarial network with the hopes of generating convincing “fake” data for biometrics. This will be done should we have issues collecting enough biometric data to train the meltdown prediction model.

App and Database: The database will receive and store all the information the hardware sends it. This will include the GPS location and other readings from the sensors. The app will then present all of this information to the guardian. The guardian will be able to see the location of the individual wearing the device as well as all other sensor readings. If a meltdown is predicted to occur, an alert will be pushed to the mobile application, informing the parent/guardian of the situation.

## 3.4. Modes of Operations

There is only one mode of operation for the system, which is meltdown mitigation. We are intending to provide end-to-end support for individuals with autism as well as their caregivers. The device will operate the same way at all times. An alert will be generated on the mobile application if the device infers that the user is likely to have a meltdown, and an audio recording will be played on the device.

## 3.5. Users

The 12th Man is marketed to the guardians/care-givers of individuals who are diagnosed with Autism Spectrum Disorder. The 12th Man will be used by the person with Autism with the intent of improving quality of life. The device will be worn on the waist along with a bluetooth chest band to sense the heartbeat. The app will be easy to use with all the essential information displayed on the home page. The guardian/caregiver and the individual diagnosed with ASD will benefit from the 12th Man since the guardian/caregiver will be more informed of their dependent’s status and the user will have more security. User installation will not be complex as instructions will guide the user and guardian/caregiver to utilizing the 12th Man.

## 3.6. Support

The users will receive a manual with instructions on how to equip the 12th Man wearable on the individual. Provided the sensors are able to collect biometric and environmental data properly, we may include alternative options of wearing the device. The user manual will also include battery life information, cleaning instructions, and warnings. Warnings will be provided to maintain the life span of the 12th Man such as mentioning that the device will not be water-proof and would not be ideal in a water-based environment. Furthermore, we will provide instructions on downloading the mobile application and linking it to the 12th Man device for guardian/caregiver use. The user manual will also have instructions on how to interact with the mobile application to view alerts and the corresponding data retrieved from the device. In the future, it may prove beneficial to have a live call center that a person can receive customer support from.

# 4. Scenario(s)

## 4.1. People with Autism

The main usage of the 12th Man is to be worn by people with autism to help them mitigate a meltdown before it occurs. When people with autism are out in public, they can get into situations that can be stressful and overwhelming. When this happens, a meltdown can occur. By monitoring the environment and the biometrics of the wearer, The 12th Man will be able to detect when they are about to have a meltdown. If a meltdown is detected, the device will guide the individual with grounding exercises to calm them down while sending a meltdown alert to the guardian through the mobile application. The guardian will also receive the individual’s location for the case of wandering.

## 4.2. People with Panic Attacks

Another use of the 12th Man could be to detect panic attacks. Since meltdowns can exhibit similar physiological responses as a panic attack does, the device may be used interchangeably. Panic attacks can be caused by an overwhelming amount of stimuli, like crowded areas or loud noises. In addition, panic attacks lead to an increase in heart rate and a shortness of breath. The 12th man can detect when these things are happening and can notify the user of an impending panic attack. The device can also contact a loved one through the app via an alert to let them know that the user is about to or having a panic attack.

## 4.3. Exercise

The 12th man can also be used by people who are exercising or doing physical activities. By tracking the user’s heartbeat and their location, a program can be added to the app to document and show their workout. Additionally, if someone is climbing a mountain, an application can be added to make sure the climber is alright. By tracking the user's heartbeat, the 12th Man can tell the wearer if their heart rate is slowing due to a lack of oxygen.

# 5. Analysis

## 5.1. Summary of Proposed Improvements

- The device will have a heartbeat sensor to detect when the individual’s heartbeat is speeding up or slowing down. Either scenario could lead to a meltdown.
- The audio inputs, temperature gauge, and accelerometer will give the system more data about the environment the individual is in. For example, determining if the individual is inside or outside, if they are moving, or determining how many people are near them.
- A more advanced GPS in the device will be able to track the user's location more precisely.
- The app will be able to collect all the input data and present it to the guardian of the wearer. The app will show the wearers location and whenever they have a meltdown or if they are about to have a meltdown.
- The AI system in the device will be able to take all the environmental inputs and accurately identify the environment the wearer is in.

## 5.2. Disadvantages and Limitations

- Sensor data could be unreliable due to bad readings and noise on the signals.
- The device will only be able to last as long as the battery lasts.
- The AI may not be able to detect the environment accurately all the time.
- Input lag from the device to the database to the app and back again may make it difficult to have real time readings.
- Some people may not want to wear the device.
- The wearer could forget to charge the device and the power dies.
- Users may have a hard time understanding how the device works.
- Grounding exercises may not be enough to stop the meltdown.
- Not water resistant

## 5.3. Alternatives

- An alternate solution could be having someone look after the individual with autism everyday. A trade-off would be having to pay this person every day to watch the individual.
- Trying to inform the public about meltdowns of people with autism. But many people will just ignore the information or could never even hear it. Plus this would cost a lot of
money to spread this information.
- The person with autism could also never leave their home and avoid situations that could cause a meltdown entirely. However, this would mean the individual would not live an ideal lifestyle.
- Just let the meltdown happen and deal with the consequences.

## 5.4. Impact

- This device will help those with autism by preventing and mitigating meltdowns. When the wearer is about to have a meltdown, the device will lead them into grounding exercises to calm the individual.
- Quality of life for people with autism will improve greatly. Now they can go out into public with more security. They know that if they have a meltdown they won’t be alone, that the 12th Man will help them. Also they will feel safe knowing that their guardian will be notified and ready to help if it is needed.
- The guardians of the austistic individual would worry less because they will be alerted when the individual has a meltdown and that a mitigation process has been implemented. The guardian will receive the individual’s location.

- People around the wearer of the device will also learn what situations can cause a meltdown. When someone sees the device calming someone down, then that person will become more aware of what environments can cause a meltdown.

# Mitigating Autistic Meltdowns

## Joshua Kao, Jason Kroslowitz, Noah Lockhart, Andres Perez

## FUNCTIONAL SYSTEM REQUIREMENTS

### REVISION 1

### 23 February 2022

FUNCTIONAL SYSTEM REQUIREMENTS

FOR

# Mitigating Autistic Meltdowns

PREPARED BY:

_____________________________
Team 12 | Date

APPROVED BY:

_____________________________
Josh Kao | Date

_____________________________
Prof. S. Kalafatis | Date

_____________________________
Eric Robles | Date

### Change Record

Rev . | Date | Originator | Approvals | Description
-1 | [2/23/2022] | [Team 12] | | Draft Release

### Table of Contents

Appendix A Acronyms and Abbreviations |

### List of Figures

# 1. Introduction

## 1.1. Purpose and Scope

Meltdowns in the Autistic community have been a debilitating issue affecting the quality of life for individuals with Autism and their loved ones. The intention of the 12th Man is to improve quality of life for individuals with Autism through a safe, discreet, and user-friendly device that autonomously predicts and mitigates meltdowns. The 12th Man is intended for those who have ASD but it can also be used by individuals who suffer from panic attacks. Figure 1 shows a proposed block diagram of the project from CONOPS.


Figure 1: The 12th Man block diagram

The 12th Man is a three stage system composed of a wearable device, artificial intelligence, and mobile application/database. The wearable device shall be composed of a microcontroller, sensors, and a rechargeable battery. Sensors shall monitor the heartbeat, speed, location, and surrounding noise of the wearer. A Raspberry Pi 4 will then send the data to the artificial intelligence, which shall make a prediction about whether a meltdown is likely to occur. If a meltdown is likely to occur, a recording from a loved one will be played through speakers on the wearable. The wearable will also store the data it collects in a remote database. This database will be accessible by a mobile application, which shall provide parents/guardians with information regarding the location and meltdown status of their dependent.


Figure 2: The 12th Man Wearable Device (Concept Image)

## 1.2. Responsibility and Change of Authority

The team leader, Joshua Kao, will have the responsibility of ensuring that all the requirements are met. Any proposed changes to the requirements shall be vetted by each team member, and passed on to our sponsor, MarkusAI, for verification and approval. Team members will each have the responsibility of ensuring that their individual subsystems function as outlined in this document. Subsystem responsibility is as follows:

Joshua Kao | Dataset Collection, Microcontroller/Sensors
Jason Kroslowitz | Artificial Intelligence
Andres Perez | Power System
Noah Lockhart | Mobile App and Database

# 2. Applicable and Reference Documents

## 2.1. Applicable Documents

Document Name | Revision/Release Date | Publisher
Raspberry Pi Model 4 Datasheet | Release 1 - June 2019 | Raspberry Pi Ltd.
TensorFlow Documentation | 1.10 | Google Brain Team
‘Meltdowns’, surveillance and managing emotions; going out with children with autism | Release 1 - September 2010 | US National Library of Medicine and National Institute of Health

## 2.2. Reference Documents

Document Name | Revision/Release Date | Publisher
50 of most important Raspberry Pi Sensors and Components | July 20, 2020 | Raspberry Pi Tutorials
Introduction to Raspberry Pi 4: Tackling the Basic Electronic Kits With the Raspberry Pi 4 | May 26, 2020 | Device Plus Editorial Team
Meltdown/Tantrum Detection System for Individuals with Autism Spectrum Disorder | December 11, 2020 | Applied Artificial Intelligence Journal

## 2.3. Order of Precedence

In the event of a conflict between the text of this specification and an applicable document cited herein, the text of this specification takes precedence without any exceptions.

All specifications, standards, exhibits, drawings or other documents that are invoked as “applicable” in this specification are incorporated as cited. All documents that are referred to within an applicable report are considered to be for guidance and information only, except ICDs that have their relevant documents considered to be incorporated as cited.

# 3. Requirements

The following section will provide definitions of all three stages for the proof of concept we are developing. “The 12th Man” refers to the system in its entirety, including the wearable device where sensor data is collected and packaged, the mobile app and server where data is sent; stored; and viewed, and the artificial intelligence which performs inference on the data collected. The term “The 12th Man Wearable” refers to the physical device including the sensors, rechargeable battery, microcontroller, and enclosure. “The mobile application and database” refers to the subsystem where collected data is stored and made available to the user. The term “Artificial Intelligence” refers to the inference performed onboard the microcontroller to predict if a meltdown is imminent or not based on sensor readings.

## 3.1. System Definition

The 12th Man is a wearable device that shall monitor an individual with Autism to predict the occurence of meltdowns, and mitigate meltdowns should they occur. The project is composed of four subsystems, which include power systems, microcontroller/sensors, artificial intelligence, and mobile application and database.


FIgure 3: Functional System Diagram

The power system subsystem shall consist of supplying power to the sensors and microcontroller. The power supply will consist of a lithium-ion battery that will supply power to the GPS module, temperature sensor, and accelerometer. A boost converter shall boost the voltage coming from the battery to supply power to the microcontroller. The system shall have a battery charger and power-path management integrated circuit to support power management to the battery.

The microcontroller and sensor subsystem shall gather biometric data and package it into usable data. The biometric data gathered by the sensor subsystem will include the subject's location, speed, heart rate, temperature, and surrounding audio data. It should also collect gyroscopic data if needed. Following the collection of data, the microcontroller will organize the data into usable packages. The data will then be sent to the server along with the Artificial Intelligence’s prediction.

The artificial intelligence subsystem will be composed of two parts. The environment acoustic classifier shall receive audio data from the microphone sensor, and shall attempt to classify the environment. A separate artificial intelligence will take as input the data from the heartbeat sensor and the accelerometer, in addition to the output of the acoustic classifier. This model shall make a prediction on the likelihood of a meltdown occurring based on the similarity of the features it receives to the “trigger” dataset on which it is trained. (This process is highly dependent on the individual: Meltdowns can express themselves in a plethora of ways, thus it is of the utmost importance to compile a dataset of triggers specific to the individual).

The database and application subsystem contains two parts as well. The first part is the database. The database will store all the input signals that are being read to the 12th Man. The most important set of data the database will hold are the GPS coordinates and the AI meltdown prediction. The app will pull the GPS location and the meltdown prediction and display them. The user can also use the app to check the connectivity of the input functions to the database.

## 3.2. Characteristics

### 3.2.1. Functional/Performance Requirements

### 3.2.1.1 Frequency of Measurements

Each sensor in The 12th Man device shall take a measurement every five minutes. For the microphone sensor, the data collected will be time-series data, i.e. a 10 second audio recording.

Rationale: Meltdowns that are able to be mitigated will not happen instantly, but rather over an extended period of time, during which warning signs specific to the individual are exhibited. The AI will attempt to learn what the “rumble stage” looks like in an individual and help stop it from progressing.

### 3.2.1.2 Accuracy of Meltdown Predictions

The 12th Man custom artificial intelligence shall meet a threshold objective of 90% correct identification of meltdown probability. When an individual exhibits any one of their several warning signs of meltdown that the AI has been trained to recognize, a meltdown should be predicted to be highly likely.

Rationale: If an individual is going to have a meltdown, it is of the utmost importance that it is predicted with high accuracy so that mitigation can begin immediately. Failing to correctly identify, mitigate, and provide alerts for a meltdown to parents/guardians could be devastating to the individual’s health and safety.

### 3.2.1.3 System Operation Time Constraint

The 12th Man will have a battery life of five hours. After this amount of time, the device will need to be recharged.

Rationale: The device will be able to function for five hours allowing the guardian of the individual to monitor one in the event that the individual with autism is to be unsupervised.

### 3.2.1.4 Wireless Communication

The 12th Man and the app must have a strong 4G connection at the minimum, or be connected to wifi at any given time.

Rationale: The device will send the data to the SQL database through the wifi connection. The database will use this data in order to predict if a meltdown will happen. If a meltdown is about to occur then the app will be notified, through the internet connection.

### 3.2.1.5 System Latency

The data collected by the sensors on the microcontroller and the prediction made by the AI on this data must be made efficiently and transmitted to the database and the mobile application with minimal latency. (10 seconds at the most).

Rationale: When someone is at the beginning stages of a meltdown, then the device must be able to predict this quickly and begin grounding exercises right away (a few seconds could be the difference between the meltdown being mitigated and the meltdown escalating beyond the point of control). Similarly, the parent/guardian will need to be notified as soon as possible if a meltdown is likely to occur.

### 3.2.2. Physical Characteristics

### 3.2.2.1 Mass

The mass of The 12th Man wearable shall be less than or equal to 1 kilogram.

Rationale: The device shall not be cumbersome to the individual. Rather, we are attempting to provide a minimal experience that is discreet.

### 3.2.2.2 Volume Envelope

The volume envelope of The 12 Man wearable shall be less than or equal to 170 mm in length, 112 mm in width, and 50 mm in height. The wearable device will consist of a 3D printed enclosure housing the microcontroller, power system, and sensors.

Rationale: The system must be able to hold all components while still being discreet for
the user.

### 3.2.2.3 Heartbeat Sensor and Device Placement

The heartbeat sensor is unique in that it is not physically connected to the wearable as the other sensors are, but rather, shall be worn around the chest using a strap. The wearable itself shall be placed on the hip and shall feature a strap with a buckle.

Rationale: Heartbeat measurements are most accurate using a sensor that is placed directly across the chest, such as the one that we will be using. Additionally, we determined the most discreet location for the wearable to be the hip.

### 3.2.3. Electrical Characteristics

### 3.2.3.1 Inputs

The inputs that The 12th Wearable is able to handle and gather is the power supplied by the components as well as digital data collected from sensors. The sensors will communicate with the microcontroller to receive data .

Rationale: By design, the wearable device is able to be properly powered and readily available to gather data.

### 3.2.3.2 Power Consumption

The maximum peak power of the system shall not exceed 15W watts. The components will not need to consume a large amount of power to function which shall allow the battery to maintain sustainable battery life. The microcontroller will be the notable component that would draw the most current thus have the highest power consumption.The battery shall then be recharged when there is insufficient energy for the device to consume.

Rationale: The demanding power consumption will not exceed what is required for each component to function properly to ensure the battery shall be sufficient to power the device after a full recharge.

### 3.2.3.3 Input Voltage Level

The input voltage level of each component shall be in between 3.6V-5V.

Rationale: The battery will be a 3.7V Lithium Ion battery and shall supply power to sensors while the microcontroller shall be supplied with 5V after stepping up voltage coming from the battery with a boost converter.

### 3.2.3.4 System Data Output

Data collected by the wearable device by the GPS module, temperature sensor, heart beat sensor, accelerometer, and microphone. Data will be stored in a database for the mobile application to fetch. The database will hold GPS coordinates, and the AI predictions of a meltdown.

Rationale: The 12th Man shall include a mobile application for users to view alerts and location of the individual wearing The 12th Man.

### 3.2.3.5 System Audio Output

The 12th Man wearable shall play an audio recording from a loved one when a meltdown is predicted.

Rationale: This would help mitigate a meltdown however the speaker may draw more current.

### 3.2.3.6 Wiring

The power supply components and sensors shall be connected on a printed circuit board or PCB.

Rationale: A printed circuit board will help make the wearable device as compact as possible.

### 3.2.4. Environmental Requirements

### 3.2.4.1 Wind

The artificial intelligence system that does acoustic classification of the environment in which the individual is located is highly susceptible to wind. Should the individual be in a windy environment, the acoustic classifier will classify the environment as such, regardless of if there is a large conversation also occurring (i.e. failing to classify a large outdoor gathering, which poses danger of overstimulation, due to large amount of wind noise).

### 3.2.4.2 Rain

The 12th Man is not waterproof. The user must be cautious in wet environments.

Rationale: Exposure to water may cause short circuiting in the wearable device resulting in damaged components.

### 3.2.5. Failure Propagation

### 3.2.5.1 Diagnostics

The 12th Man will show the biometrics collected by the wearable on the mobile app. If biometrics are not visible the user can identify if any sensors are no longer receiving data or if there is a connectivity issue.

### 3.2.5.2 Database Connection

The user will be able to see if the app is not connected to the database properly.

Rationale: Allows users to see if the app is able to pull data.

### 3.2.5.3 GPS Connection

The user will be notified if the GPS coordinates are not being sent or received correctly.

Rationale: The location of the wearer must be presented in the app at all times.

### 3.2.5.4 Input Sensor Signals

A test will be added to make sure that each device that is taking an input, the accelerometer, microphone, GPS, heart rate sensor, is sending data to the database.

Rationale: If any of the input signals are no longer sending data, then the device will not be able to detect meltdowns.

# 4. Support Requirements

### 4.1.1 User Interface

Users will need to have an Android smartphone to obtain and run the app. The user should also be able to afford and access a data plan or wifi.

### 4.2.1 Usage of Wearable Device

The user must be wearing the heart rate sensor on their chest for the system to work reliably.

### 4.3.1 Maintenance

The user should check reading daily to see if the device is working properly before going into an unsupervised area.

# Appendix A

AI | Artificial Intelligence
ASD | Autism Spectrum Disorder

CONOPS | Concept of Operation
GPS | Global Positioning System
I/O | Input/Output
mm | Millimeters
PCB | Printed Circuit Board
SQL | Structured Query Language
V | Volts
W | Watts
4G | Mobile Communication Standard

# Mitigating Autistic Meltdowns

## Joshua Kao, Jason Kroslowitz, Noah Lockhart, Andres Perez

## INTERFACE CONTROL DOCUMENT

### REVISION 1 23 February 2022

INTERFACE CONTROL DOCUMENT

FOR

# Mitigating Autistic Meltdowns

PREPARED BY:

_____________________________
Team 12 | Date

APPROVED BY:

_____________________________
Josh Kao | Date

_____________________________
Prof. S. Kalafatis | Date

_____________________________
Eric Robles | Date

### Change Record

Rev. | Date | Originator | Approvals | Description
-1 | [2/23/2022] | [Team 12] | | Draft Release

### Table of Contents

### List of Figures

# 1. Overview

The Interface Control Document or ICD for The 12th Man will go into detail regarding how the subsystems in the Concept of Operations and requests from the Functional System Requirements will be fulfilled. The ICD will provide characteristics of the various stages of our project and how they will interact between each other including communications, component location, and electrical characteristics.

# 2. References and Definitions

## 2.1. References

MIL-STD-810F
Environmental Engineering Considerations and Laboratories Tests 1 Jan 2000
Change Notice 2
30 Aug 2002

American National Standard for VME64 (ANSI/VITA 1-1994 (R2002))
4 Apr 1995

American National Standard for VME64 Extensions (ANSI/VITA 1.1-1997) 7 Oct 1998

## 2.2. Definitions

AI | Artificial Intelligence
ASD | Autism Spectrum Disorder
CONOPS | Concept of Operation
GPS | Global Positioning System
IC | Integrated circuit
I/O | Input/Output
mA | Milliampere
mAH | Microamp hours
mm | Millimeters
mW | Milliwatt
Li | Lithium
PCB | Printed Circuit Board
SQL | Structured Query Language
TBD | To Be Determined
V | Volts
W | Watts
4G | Mobile Communication Standard

# 3. Physical Interface

## 3.1 Weight

### 3.1.1 Weight of the Sensors and microcontroller

The sensors and microcontroller have a combined weight of less than half a kilogram This allows for the wearable device to sit comfortably on the user's waist.

Component | Weight(grams)
Raspberry Pi 4 (microcontroller) | 46 grams
MPU6050(accelerometer) | 6.208546
GPS Module GPS NEO-6M | 9.8089
Polar H9 Heartrate Monitor | 100
USB 2.0 Mini Microphone | 22.9631
DS18B20 Temperature Sensor | 22.96

### 3.1.2 Weight of Power System Components

Component | Weight(grams)
Li-ion Battery | 158.757
Battery Charger and Power-Path Management IC | 0.05
Boost Converter | TBD
AC/DC adapter | TBD

## 3.2 Dimensions

### 3.2.1 Dimensions of Sensors and Microcontroller

The biometric sensors will fit on a PCB board inside a 3D printed enclosure. The enclosure will be less than or equal to 170 mm in length, 112 mm in width, and 50 mm in height.

Component | Length(mm) | Width(mm) | Height(mm)
Raspberry Pi 4 | 88 | 58 | 19.5
MPU6050 | 20.066 | 16.51 | 9.906
GPS Module GPS NEO-6M | 27.686 | 100.076 mm | 22.606
Polar H9 Heartrate Monitor | 34.036 | 65.024 | 9.906
USB 2.0 Mini Microphone | 22.29 | 18.45 | 7.12
DS18B20 Temperature Sensor | 60.96 | 15.24 mm | 2.54

### 3.2.2 Weight of Power System Components

Component | Length(mm) | Width(mm) | Height(mm)
Li-ion Battery | 109.982 | 59.944 | 9.906
Battery Charger and Power-Path Management IC | 3.0 | 3.0 | 0.9
Boost Converter | TBD | TBD | TBD
AC/DC adapter | TBD | TBD | TBD

## 3.3. Mounting Locations

### 3.3.1. Mounting of Sensors

All sensors will be placed on the PCB board such that there is no interference with their data collection. The microphone and temperature sensors will be partially external to allow for accurate noise and temperature collection without interference. The other sensors are not location dependent.

### 3.3.2. Mounting of Microcontroller

The microcontroller will be inside a 3D printed enclosure below the PCB board. The wiring from the microcontroller to the sensors will also be tucked inside said enclosure and spaced apart to avoid any potential for short circuits.

### 3.3.3. Mounting of Heartbeat Sensor

The heartbeat sensor should be around the user's chest to ensure the best heartbeat possible.

### 3.3.4. Mounting of the device

The 12th man device should be attached to the user's pants or belt around their waist without anything covering the microphone. This to ensure the best audio quality of the surrounding noise is collected.

# 4. Electrical Interface


Figure 1. Electrical block diagram

## 4.1. Primary Input Power

The Lithium Ion battery shall be charged and recharged by an AC/DC adapter in which a battery charger and power path management integrated circuit shall be connected to the 3.7V 10,500 mAh battery. The battery shall supply power to the GPS module, temperature sensor, and accelerometer. The battery shall provide input voltage to a boost converter to boost the voltage output to 5V and supply power to the Raspberry Pi. The microphone shall be powered by the microcontroller via usb. The heart rate sensor is an internally powered sensor.

## 4.2. Voltage and Current Levels

### 4.2.1. Voltage, Current, and Power Consumption

Component | Voltage(V) | Current(mA) | Power(mW)
Raspberry Pi 4b | 5 | 3000 | 15000
GPS Module | 3.6-5V | Capture 45mA/5.0V | TBD
Temperature Sensor | 3-5.25 | TBD | TBD

Accelerometer | 3.3V | TBD | TBD
Microphone + Speaker | TBD | TBD | TBD

The current drawn by the GPS module, temperature sensor, accelerometer is assumed to not draw significant current. The Raspberry Pi 4b will draw a significant amount of current. The battery shall have a capacity of 10500mAh to ensure sustainable battery life for the device.

## 4.3. Signal Interfaces

### 4.3.1. Input Sensors

The GPS module, ambient temperature sensor, heart rate sensor, accelerometer, and microphone shall communicate with the Raspberry Pi so that data can be collected.

### 4.3.2. Output Signals

For the purpose of mitigation, The 12th Man device should have an output speaker that can be used to play audio recordings. Said audio recordings are grounding exercises recorded by loved ones. The Raspberry Pi should be able to communicate with the speaker so that it can be utilized as an output device.

## 4.4. User Control Interface

### 4.4.1. Database Signals

The mobile application will provide the user with a control interface. This interface will provide the user the ability to tether their mobile application to the 12th Man device their dependent will be wearing. The parent/guardian shall then be able to view the data collected by the device and an indication of the meltdown status of their dependent.

The user will be able to check the status of each input signal. The user will see if all the database is receiving data from the GPS, accelerometer, ambient temperature sensor, heart rate sensor, and microphone.

### 4.4.2. Physical Device

The individual with Autism who is wearing the device is not provided a control interface whatsoever, and is simply responsible for wearing the device.

# 5. Communications / Device Interface Protocol

## 5.1. Wireless Communications (WiFi)

Wifi connection will be achieved using the Raspberry Pi 4 microcontroller. The Raspberry Pi 4 microcontroller utilizes a Wifi package that allows for wireless connectivity. The wifi connection will allow the device to take inputs from the GPS, accelerometer, heart rate sensor, temperature gauge, and microphone and send that information to the database. The database will use this data to identify if a meltdown will occur. If a meltdown is about to happen, a signal will be sent to the device to start the grounding exercises. The database will also send information from the database to the app using a HTTP connection, while the app is connected to the internet.

## 5.2. Microcontroller Input and Output

The raspberry pi includes an assortment of digital and analog inputs. Analog Input pins take in voltage at 5v and also take in signals from an accelerometer and GPS. The digital input pins receive microphone data via bluetooth and USB ports. All the following pins meet the requirements for the sensors used above.

## 5.3. Sensor Communication

The sensors will primarily communicate through pins with the Raspberry Pi using an I2C connection. The heartbeat sensor will use the bluetooth module attached to the Raspberry Pi and the microphone will use the USB module included with the Raspberry Pi.

## 5.4. Device Peripheral Interface

The database will be connected to the mobile app through a HTTP connection. This is a reliable way to send data from a SQL database to an application.

# Mitigating Autistic Meltdowns

## Joshua Kao, Jason Kroslowitz, Noah Lockhart, Andres Perez

# Execution and Validation Plan

### REVISION – Draft 1

### 23 February 2022

# 1. Execution Plan

| Jan-2 4 | Jan-31 | Feb-7 | Feb -14 | Feb -21 | Feb -28 | Mar -7 | Mar-14 | Mar-21 | Mar -28 | Apr-4 | Apr-11 | Apr-18 | Apr-25 | Apr-29

Understanding Concept of Project

Research and Planning

Write ConOps | | | | | | | | | | | | | | | | Missed Execution
Acquire Microcontroller | | | | | | | | | | | | | | | | Planned
Acquire sensors | | | | | | | | | | | | | | | | In Progress
Meet w/ Special Education Specialists | | | | | | | | | | | | | | | | Completed

Write FSR and ICD

Have all sensors interface with microcontroller

Collect HR & accel. data and compile a biometric dataset

Create outline for app

Midterm Presentation

Evaluate performance of acoustic CNN on Raspberry Pi

Begin training an ANN to recognize triggers

Test Sensor Loads (Voltage, amperage, and watts)

Database set up

Complete Circuit Design for power supply

Practice and Learn Altium Software

Test Power Supply Components

Packet Sensor Data into usable data

Complete PCB Design

Acquire AC/DC adapter

Send Order for PCB

Status Update Presentation

Solder Components to PCB

Database can receive and store data from microcontroller

Final Presentation

# 2. Validation Plan

Task | Status | Responsibility
Interface Sensors with Microcontroller | In Progress | Joshua
Collect HR & accel, data and compile (biometric) trigger dataset (ML) | In Progress | Joshua & Jason
Interview and research data from Special Education Specialists | In Progress | Joshua & Jason
An Outline of mobile application | In Progress | Noah
Verify sensor sizes according to wearable constraints | In Progress | Joshua & Andres
Evaluate acoustic CNN performance on correctly classifying environments | In Progress | Jason
Format/package data into packets (for transmission to database) | Not Completed | Joshua
Send data to database | Not Completed | Joshua & Noah
Preprocess and clean ML dataset; remove outliers and zero values | Not Completed | Jason & Joshua
Setting up Database | Not Completed | Noah
Augment trigger dataset to include acoustic triggers | Not Completed | Jason
Connecting App to Database | Not Completed | Noah
Begin training ANN to recognize meltdown triggers (combination of biometric inputs and acoustic CNN output). | Not Completed | Jason
Displaying App on Phone | Not Completed | Noah
Provide Proper Input Voltage and Current Levels(Sensors) | Not Completed | Andres and Joshua
Provide Proper Input Voltage and Current Level(Microcontroller) | Not Completed | Andres & Joshua

Fine tune prediction models | Not Completed | Jason
Create Functional Rechargeable Battery | Not Completed | Andres
Provide Sustainable Battery Life(5hours) | Not Completed | Andres

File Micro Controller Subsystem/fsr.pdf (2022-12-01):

# Mitigating Autistic Meltdowns

## Joshua Kao, Jason Kroslowitz, Noah Lockhart, Andres Perez

## FUNCTIONAL SYSTEM REQUIREMENTS

### REVISION 1 23 February 2022

Functional System Requirements | Revision 1
Mitigating Autistic Meltdowns
FUNCTIONAL SYSTEM REQUIREMENTS

FOR

# Mitigating Autistic Meltdowns

PREPARED BY:

_____________________________
Team 12 | Date

APPROVED BY:

_____________________________
Josh Kao | Date

_____________________________
Prof. S. Kalafatis | Date

_____________________________
Eric Robles | Date

### Change Record

Rev . | Date | Originator | Approvals | Description
-1 | [2/23/2022] | [Team 12] | | Draft Release

### Table of Contents

Appendix A Acronyms and Abbreviations |
Appendix B Definition of Terms |
Appendix C Interface Control Documents |

### List of Figures

# 1. Introduction

## 1.1. Purpose and Scope

Meltdowns in the Autistic community have been a debilitating issue affecting the quality of life for individuals with Autism and their loved ones. The intention of the 12th Man is to improve quality of life for individuals with Autism through a safe, discreet, and user-friendly device that autonomously predicts and mitigates meltdowns. The 12th Man is intended for those who have ASD but it can also be used by individuals who suffer from panic attacks. Figure 1 shows a proposed block diagram of the project from CONOPS.


Figure 1: The 12th Man block diagram

The 12th Man is a three stage system composed of a wearable device, artificial intelligence, and mobile application/database. The wearable device shall be composed of a microcontroller, sensors, and a rechargeable battery. Sensors shall monitor the heartbeat, speed, location, and surrounding noise of the wearer. A Raspberry Pi 4 will then send the data to the artificial intelligence, which shall make a prediction about whether a meltdown is likely to occur. If a meltdown is likely to occur, a recording from a loved one will be played through speakers on the wearable. The wearable will also store the data it collects in a remote database. This database will be accessible by a mobile application, which shall provide parents/guardians with information regarding the location and meltdown status of their dependent.


Figure 2: The 12th Man Wearable Device (Concept Image)

## 1.2. Responsibility and Change of Authority

The team leader, Joshua Kao, will have the responsibility of ensuring that all the requirements are met. Any proposed changes to the requirements shall be vetted by each team member, and passed on to our sponsor, MarkusAI, for verification and approval. Team members will each have the responsibility of ensuring that their individual subsystems function as outlined in this document. Subsystem responsibility is as follows:

Joshua Kao | Dataset Collection, Microcontroller/Sensors
Jason Kroslowitz | Artificial Intelligence
Andres Perez | Power System
Noah Lockhart | Mobile App and Database

# 2. Applicable and Reference Documents

## 2.1. Applicable Documents

Document Name | Revision/Release Date | Publisher
Raspberry Pi Model 4 Datasheet | Release 1 - June 2019 | Raspberry Pi Ltd.
TensorFlow Documentation | 1.10 | Google Brain Team

## 2.2. Reference Documents

Document Name | Revision/Release Date | Publisher
50 of most important Raspberry Pi Sensors and Components | July 20, 2020 | Raspberry Pi Tutorials
Introduction to Raspberry Pi 4: Tackling the Basic Electronic Kits With the Raspberry Pi 4 | May 26, 2020 | Device Plus Editorial Team

## 2.3. Order of Precedence

In the event of a conflict between the text of this specification and an applicable document cited herein, the text of this specification takes precedence without any exceptions.

All specifications, standards, exhibits, drawings or other documents that are invoked as “applicable” in this specification are incorporated as cited. All documents that are referred to within an applicable report are considered to be for guidance and information only, except ICDs that have their relevant documents considered to be incorporated as cited.

# 3. Requirements

The following section will provide definitions of all three stages for the proof of concept we are developing. “The 12th Man” refers to the system in its entirety, including the wearable device where sensor data is collected and packaged, the mobile app and server where data is sent; stored; and viewed, and the artificial intelligence which performs inference on the data collected. The term “The 12th Man Wearable” refers to the physical device including the sensors, rechargeable battery, microcontroller, and enclosure. “The mobile application and database” refers to the subsystem where collected data is stored and made available to the user. The term “Artificial Intelligence” refers to the inference performed onboard the microcontroller to predict if a meltdown is imminent or not based on sensor readings.

## 3.1. System Definition

The 12th Man is a wearable device that shall monitor an individual with Autism to predict the occurence of meltdowns, and mitigate meltdowns should they occur. The project is composed of four subsystems, which include power systems, microcontroller/sensors, artificial intelligence, and mobile application and database.


FIgure 3: Functional System Diagram

The power system subsystem shall consist of supplying power to the sensors and microcontroller. The power supply will consist of a lithium-ion battery that will supply power to the GPS module, temperature sensor, and accelerometer. A boost converter shall boost the voltage coming from the battery to supply power to the microcontroller. The system shall have a battery charger and power-path management integrated circuit to support power management to the battery.

The microcontroller and sensor subsystem shall gather biometric data and package it into usable data. The biometric data gathered by the sensor subsystem will include the subject's location, speed, heart rate, temperature, and surrounding audio data. It should also collect gyroscopic data if needed. Following the collection of data, the microcontroller will organize the data into usable packages. The data will then be sent to the server along with the Artificial Intelligence’s prediction.

The artificial intelligence subsystem will be composed of two parts. The environment acoustic classifier shall receive audio data from the microphone sensor, and shall attempt to classify the environment. A separate artificial intelligence will take as input the data from the heartbeat sensor and the accelerometer, in addition to the output of the acoustic classifier. This model shall make a prediction on the likelihood of a meltdown occurring based on the similarity of the features it receives to the “trigger” dataset on which it is trained. (This process is highly dependent on the individual: Meltdowns can express themselves in a plethora of ways, thus it is of the utmost importance to compile a dataset of triggers specific to the individual).

The database and application subsystem contains two parts as well. The first part is the database. The database will store all the input signals that are being read to the 12th Man. The most important set of data the database will hold are the GPS coordinates and the AI meltdown prediction. The app will pull the GPS location and the meltdown prediction and display them. The user can also use the app to check the connectivity of the input functions to the database.

## 3.2. Characteristics

### 3.2.1. Functional/Performance Requirements

### 3.2.1.1 Frequency of Measurements

Each sensor in The 12th Man device shall take a measurement every five minutes. For the microphone sensor, the data collected will be time-series data, i.e. a 10 second audio recording.

Rationale: Meltdowns that are able to be mitigated will not happen instantly, but rather over an extended period of time, during which warning signs specific to the individual are exhibited. The AI will attempt to learn what the “rumble stage” looks like in an individual and help stop it from progressing.

### 3.2.1.2 Accuracy of Meltdown Predictions

The 12th Man custom artificial intelligence shall meet a threshold objective of 90% correct identification of meltdown probability. When an individual exhibits any one of their several warning signs of meltdown that the AI has been trained to recognize, a meltdown should be predicted to be highly likely.

Rationale: If an individual is going to have a meltdown, it is of the utmost importance that it is predicted with high accuracy so that mitigation can begin immediately. Failing to correctly identify, mitigate, and provide alerts for a meltdown to parents/guardians could be devastating to the individual’s health and safety.

### 3.2.1.3 System Operation Time Constraint

The 12th Man will have a battery life of five hours. After this amount of time, the device will need to be recharged.

Rationale: The device will be able to function for five hours allowing the guardian of the individual to monitor one in the event that the individual with autism is to be unsupervised.

### 3.2.1.4 Wireless Communication

The 12th Man and the app must have a strong 4G connection at the minimum, or be connected to wifi at any given time.

Rationale: The device will send the data to the SQL database through the wifi connection. The database will use this data in order to predict if a meltdown will happen. If a meltdown is about to occur then the app will be notified, through the internet connection.

### 3.2.1.5 System Latency

The data collected by the sensors on the microcontroller and the prediction made by the AI on this data must be made efficiently and transmitted to the database and the mobile application with minimal latency. (10 seconds at the most).

Rationale: When someone is at the beginning stages of a meltdown, then the device must be able to predict this quickly and begin grounding exercises right away (a few seconds could be the difference between the meltdown being mitigated and the meltdown escalating beyond the point of control). Similarly, the parent/guardian will need to be notified as soon as possible if a meltdown is likely to occur.

### 3.2.2. Physical Characteristics

### 3.2.2.1 Mass

The mass of The 12th Man wearable shall be less than or equal to 1 kilogram.

Rationale: The device shall not be cumbersome to the individual. Rather, we are attempting to provide a minimal experience that is discreet.

### 3.2.2.2 Volume Envelope

The volume envelope of The 12 Man wearable shall be less than or equal to 170 mm in length, 112 mm in width, and 50 mm in height. The wearable device will consist of a 3D printed enclosure housing the microcontroller, power system, and sensors.

Rationale: The system must be able to hold all components while still being discreet for
the user.

### 3.2.2.3 Heartbeat Sensor and Device Placement

The heartbeat sensor is unique in that it is not physically connected to the wearable as the other sensors are, but rather, shall be worn around the chest using a strap. The wearable itself shall be placed on the hip and shall feature a strap with a buckle.

Rationale: Heartbeat measurements are most accurate using a sensor that is placed directly across the chest, such as the one that we will be using. Additionally, we determined the most discreet location for the wearable to be the hip.

### 3.2.3. Electrical Characteristics

### 3.2.3.1 Inputs

The inputs that The 12th Wearable is able to handle and gather is the power supplied by the components as well as digital data collected from sensors. The sensors will communicate with the microcontroller to receive data .

Rationale: By design, the wearable device is able to be properly powered and readily available to gather data.

### 3.2.3.2 Power Consumption

The maximum peak power of the system shall not exceed 15W watts. The components will not need to consume a large amount of power to function which shall allow the battery to maintain sustainable battery life. The microcontroller will be the notable component that would draw the most current thus have the highest power consumption.The battery shall then be recharged when there is insufficient energy for the device to consume.

Rationale: The demanding power consumption will not exceed what is required for each component to function properly to ensure the battery shall be sufficient to power the device after a full recharge.

### 3.2.3.3 Input Voltage Level

The input voltage level of each component shall be in between 3.6V-5V.

Rationale: The battery will be a 3.7V Lithium Ion battery and shall supply power to sensors while the microcontroller shall be supplied with 5V after stepping up voltage coming from the battery with a boost converter.

### 3.2.3.4 System Data Output

Data collected by the wearable device by the GPS module, temperature sensor, heart beat sensor, accelerometer, and microphone. Data will be stored in a database for the mobile application to fetch. The database will hold GPS coordinates, and the AI predictions of a meltdown.

Rationale: The 12th Man shall include a mobile application for users to view alerts and location of the individual wearing The 12th Man.

### 3.2.3.5 System Audio Output

The 12th Man wearable shall play an audio recording from a loved one when a meltdown is predicted.

Rationale: This would help mitigate a meltdown however the speaker may draw more current.

### 3.2.3.6 Wiring

The power supply components and sensors shall be connected on a printed circuit board or PCB.

Rationale: A printed circuit board will help make the wearable device as compact as possible.

### 3.2.4. Environmental Requirements

### 3.2.4.1 Wind

The artificial intelligence system that does acoustic classification of the environment in which the individual is located is highly susceptible to wind. Should the individual be in a windy environment, the acoustic classifier will classify the environment as such, regardless of if there is a large conversation also occurring (i.e. failing to classify a large outdoor gathering, which poses danger of overstimulation, due to large amount of wind noise).

### 3.2.4.2 Rain

The 12th Man is not waterproof. The user must be cautious in wet environments.

Rationale: Exposure to water may cause short circuiting in the wearable device resulting in damaged components.

### 3.2.5. Failure Propagation

### 3.2.5.1 Diagnostics

The 12th Man will show the biometrics collected by the wearable on the mobile app. If biometrics are not visible the user can identify if any sensors are no longer receiving data or if there is a connectivity issue.

### 3.2.5.2 Database Connection

The user will be able to see if the app is not connected to the database properly.

Rationale: Allows users to see if the app is able to pull data.

### 3.2.5.3 GPS Connection

The user will be notified if the GPS coordinates are not being sent or received correctly.

Rationale: The location of the wearer must be presented in the app at all times.

### 3.2.5.4 Input Sensor Signals

A test will be added to make sure that each device that is taking an input, the accelerometer, microphone, GPS, heart rate sensor, is sending data to the database.

Rationale: If any of the input signals are no longer sending data, then the device will not be able to detect meltdowns.

# 4. Support Requirements

### 4.1.1 User Interface

Users will need to have an Android smartphone to obtain and run the app. The user should also be able to afford and access a data plan or wifi.

### 4.2.1 Usage of Wearable Device

The user must be wearing the heart rate sensor on their chest for the system to work reliably.

### 4.3.1 Maintenance

The user should check reading daily to see if the device is working properly before going into an unsupervised area.

# Appendix A

AI | Artificial Intelligence
ASD | Autism Spectrum Disorder
CONOPS | Concept of Operation
GPS | Global Positioning System
I/O | Input/Output
mm | Millimeters
PCB | Printed Circuit Board
SQL | Structured Query Language
V | Volts
W | Watts
4G | Mobile Communication Standard

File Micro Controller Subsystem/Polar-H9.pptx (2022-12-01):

## Polar-H9

- Information Flow Diagram

Cron-Job
Automated process that runs all scripts on Raspberry Pi 4

Polar H9 Heart-rate monitor
Mac Address: D9:B0:Fa:49:40:87

Gatttool –t random -b
Linux commands that access information from Polar H9 in hexadecimal format

--char-write-req
Writing data

Pipeline
Move data from terminal to hr_hex.txt

hex.py
Convert Hex values to decimal

Hr_base10.txt
Final heart rate output

Polar H9 Handle
0x0011

Mac Address
How Bluetooth low energy is connected to microcontroller

--listen
Marks socket that allows for incoming connection requests

stdbuf
Marketing Manager

File io
Reading hex values and opening new file for base 10 values.

Polar H9 Value
0100

Handle
Requesting the heart rate information from device

-o0 cut –d ‘ ‘ –f 7
Separating data to make more readable

Line = line.strip()
Placing values into new file

Value
Information request from the handle

## CONTOSO

- Organization chart

Kalle Persson
HR Manager

Flora Berggren
VP Human Resources

April Hansson
Marketing Manager

Mira Karlsson
VP Marketing

Victoria Hanssen
HR Manager

Kalle Persson
Marketing Manager

Angelica Hansson
Product Manager

Mirjam Nilsson
President

Angelica Astrom
Engineering Director

Allan Mattsson
VP Technology

Kalle Persson
VP Product

Victoria Hansson
Product Manager

Jens Martensson
Product Manager

August Bergqvist
VP Finance

Ian Hansson
Accounting Manager

Victoria Persson
VP Transportation

Alexander Martensson
Accounting Manager

## CONTOSO

- Organization chart

Mirjam Nilsson
President

August Bergqvist
VP Finance

Kalle Persson
Accounting Manager

Allan Mattsson
VP Technology

Kalle Persson
Engineering Director

Flora Berggren
VP Operations

Kalle Persson
Facilities Manager

Mira Karlsson
VP Marketing

Kalle Persson
Marketing Manager

Kalle Persson
VP Product

Kalle Persson
Product Manager

Victoria Persson
VP Human Resources

Kalle Persson
HR Manager

Kalle Persson
Accounting Manager

Kalle Persson
Marketing Manager

Kalle Persson
Product Manager

Kalle Persson
HR Manager

Kalle Persson
Accounting Manager

Kalle Persson
HR Manager

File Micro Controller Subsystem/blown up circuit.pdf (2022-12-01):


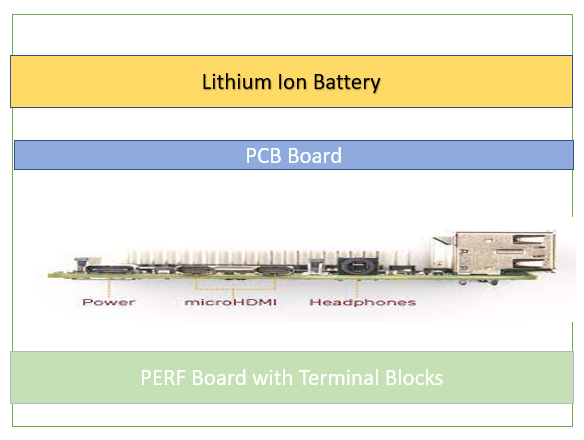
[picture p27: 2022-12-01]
Micro Controller Subsystem/High Lavel Overview.PNG

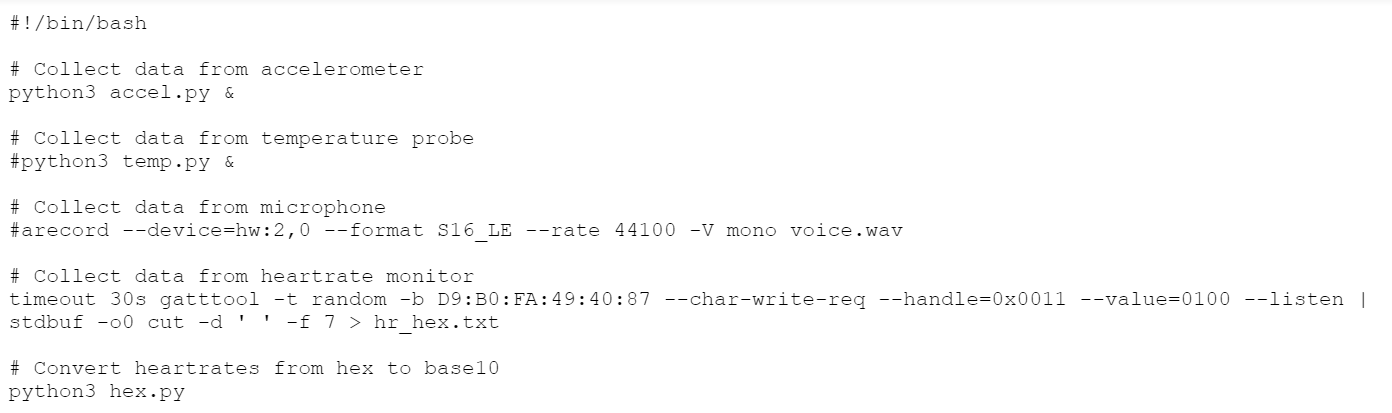
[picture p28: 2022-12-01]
Micro Controller Subsystem/datacollection.PNG

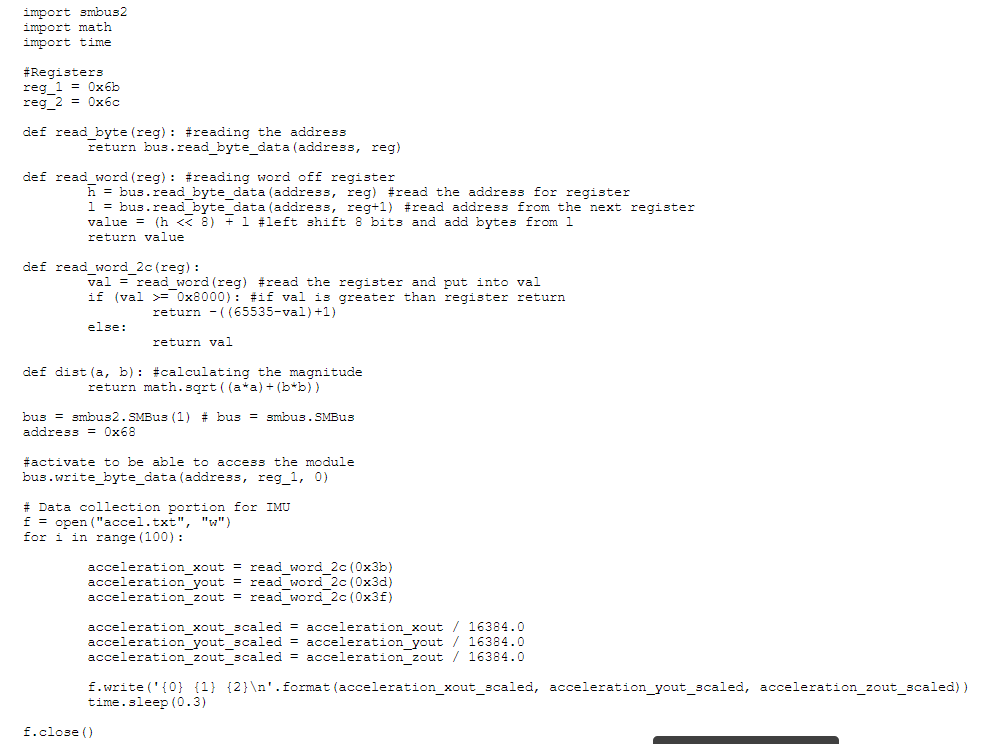
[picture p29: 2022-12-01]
Micro Controller Subsystem/accelerometer.PNG

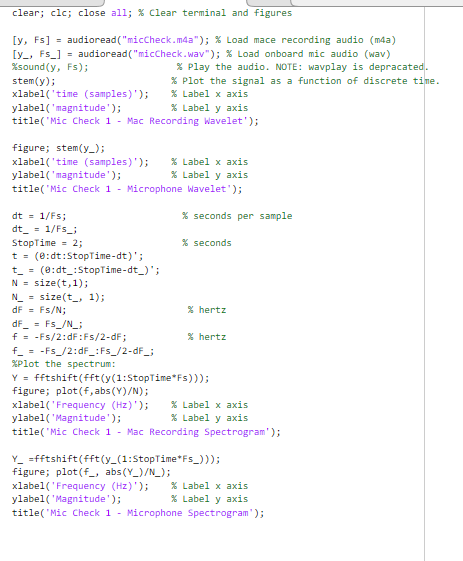
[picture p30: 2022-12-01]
Micro Controller Subsystem/matlab script.png

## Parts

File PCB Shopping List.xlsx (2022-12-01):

Care | Component Name | Component Value | Manufacture ID | Quantity | Total Price | Link
2 | USB-C Ports | N/A | ID:632723100011 | 2 | 8.74 | https://www.digikey.com/en/products/detail/w%C3%BCrth-elektronik/632723100011/5806669
1 | Battery Header | N/A | M20-9990246 | 2 | 0.28 | https://www.digikey.com/en/products/detail/harwin-inc/M20-9990246/3728226?s=N4IgTCBcDaILJgAwFoCc7FgCwDYQF0BfIA
5 | Resistor | 10k | CHP0805-FX-1002ELF | 10 | 4.7 | https://www.mouser.com/ProductDetail/Bourns/CHP0805-FX-1002ELF?qs=lc2O%252BfHJPVaDI6gsPdDtfw%3D%3D
1 | Resistor | 20kohm | RCS120620K0FKEA | 2 | 0.66 | https://www.mouser.com/ProductDetail/Vishay-Dale/RCS120620K0FKEA?qs=6AVTNucw1PXEVYqowgGoNA%3D%3D
1 | Resistor | 1kohm | RCC12061K00FKEA | 2 | 0.76 | https://www.mouser.com/ProductDetail/Vishay-Dale/RCC12061K00FKEA?qs=IS%252B4QmGtzzoI2b9zl4DztQ%3D%3D
1 | Resistor | 41.2kohm | RN73C2A41K2BTDF | 2 | 2.08 | https://www.mouser.com/ProductDetail/TE-Connectivity-Holsworthy/RN73C2A41K2BTDF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
2 | Capacitor | 2.2uF | C3216X7R1V225K160AE | 4 | 2.76 | https://www.mouser.com/ProductDetail/TDK/C3216X7R1V225K160AE?qs=nQSIdc08i%252Bcchfc%2FLB33PA%3D%3D
2 | Capacitor | 10uF | CNA5L1X7R1E106K160AE | 4 | 4.36 | https://www.mouser.com/ProductDetail/TDK/CNA5L1X7R1E106K160AE
1 | Capacitor | 47nF | C1206C561KDGACAUTO | 3 | 2.67 | https://www.mouser.com/ProductDetail/KEMET/C1206C561KDGACAUTO?qs=MyNHzdoqoQL%252BgGDPneTOTA%3D%3D
2 | Capacitor | 47uF | C2012X5R1A476M125AC | 4 | 3.12 | https://www.mouser.com/ProductDetail/TDK/C2012X5R1A476M125AC?qs=LcTL%2F5vFEzGyFw5hxP%2FMXw%3D%3D
2 | Capacitor | 22uF | C2012X5R1A226M125AB | 4 | 2 | https://www.mouser.com/ProductDetail/TDK/C2012X5R1A226M125AB?qs=LcTL%2F5vFEzEl81ah%2FUQuuw%3D%3D
2 | Inductor | 1uH | SPM6530T-1R0M120 | 4 | 4.92 | https://www.mouser.com/ProductDetail/TDK/SPM6530T-1R0M120?qs=chjFIDm9dbpAC3nWIRa%252B5A%3D%3D
2 | LED | 2mA | AA3021LSYSK/J3-TR | 4 | 2.32 | https://www.mouser.com/ProductDetail/Kingbright/AA3021LSYSK-J3-TR?qs=Oo40KB9lBTmS1V8p5PSO3Q%3D%3D
 |  |  |  |  | 39.37

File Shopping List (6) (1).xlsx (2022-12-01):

Order Date: | Item | Quantity | Link | Cost | Names | ECEN 403 | Group 12
2022-02-09 | Heart beat sensor | 1 | https://www.heartratemonitorsusa.com/products/polar-h7-transmitters-all?variant=48011568981 | $59.95 | Joshua Kao
2022-02-09 | Bluetooth Adaptor | 1 | https://www.amazon.com/gp/product/B007GFX0PY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 | $15.09 | Andres Perez
2022-02-09 | Microphone | 1 | https://www.amazon.com/SunFounder-Microphone-Raspberry-Recognition-Software/dp/B01KLRBHGM | $7.99 | Jason Kroslowitz
2022-02-09 | Temperature | 1 | https://www.amazon.com/DS18B20-Temperature-Waterproof-Stainless-Raspberry/dp/B087JQ6MCP | $9.99 | Noah Lockhart
2022-02-09 | GPS | 1 | https://www.amazon.com/Microcontroller-Compatible-Sensitivity-Navigation-Positioning/dp/B07P8YMVNT | $11.59
 |  |  | Total Cost | $104.61
 |  |  | Total Remaining | $295.39
2022-02-21 | Lithium Ion Battery | 1 | https://www.amazon.com/dp/B095BTSMYH/ref=emc_b_5_t?th=1 | 25.99
2022-02-21 | Battery Charger and Power Management | 1 | https://www.digikey.com/en/products/detail/texas-instruments/BQ24232HRGTR/4733923 | 2.3
 |  |  | Total Cost | 28.29
 |  |  | Total Remaining | 267.1
2022-03-07 | Boost Converter | 2 | https://www.mouser.com/ProductDetail/Texas-Instruments/TPS61032PWP?qs=Gse6rAGbi7%252B07XodIBvuHQ%3D%3D | 7.5
 |  |  | Total Cost | 7.5
 |  |  | Total Remaining | 259.6
2022-03-10 | Fuel Gauge | 1 | https://www.digikey.com/en/products/detail/texas-instruments/BQ27542DRZT-G1/6571628 | 5.06
2022-03-10 | Lipo Battery | 1 | https://ydlbattery.com/products/1160100-10000mah-li-ion-battery?currency=USD&variant=40175451570329 | 20.99
 |  |  | Total Cost | 26.05
 |  |  | Total Remaining | 233.55
2022-03-30 | P Channel Mosfet | 2 | https://www.mouser.com/ProductDetail/Vishay-Semiconductors/SI2371EDS-T1-GE3?qs=vgn07B5hXatICifqRPHaiw%3D%3D | 0.92
 |  |  | Total Cost | 0.92
 |  |  | Total Remaining | 232.63
2022-04-06 | PEC03SAAN | 2 | https://www.digikey.com/en/products/detail/sullins-connector-solutions/PEC03SAAN/859156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 | 0.44
 |  |  | Total Cost | 0.44
 |  |  | Total Remaining | 232.19
44662 | 732k ohm Resistor throughole | 2 | https://www.mouser.com/ProductDetail/Vishay-Dale/CCF55732KFKE36 | 0.4
44662 | 1uH Inductor | 2 | https://www.mouser.com/ProductDetail/Bourns/RLB0912-1R0ML?qs=4vvWAaIu%2Fq4ZBxj%2FYdtPVQ%3D%3D | 1
 |  |  | Total Cost | 1.4
 |  |  | Total Remaining | 230.79
2022-08-08 | Battery Charger IC BQ25300RTER | Quantity: 3 | BQ25300 | Buy TI Parts | TI.com (https://www.ti.com/product/BQ25300/part-details/BQ25300RTER) | 2.1
2022-08-08 | Battery Charger IC BQ24061DRCR | Quantity: 2 | BQ24061DRCR Texas Instruments | Mouser (https://www.mouser.com/ProductDetail/Texas-Instruments/BQ24061DRCR?qs=iSMark9AYDWfy1BtqtQVWg%3D%3D) | 6.02
2022-08-08 | Battery Charger IC BQ25303JRTER | Quantity: 1 | BQ25303JRTER Texas Instruments | Mouser (https://www.mouser.com/ProductDetail/Texas-Instruments/BQ25303JRTER?qs=DRkmTr78QARA1C7%2F12q3og%3D%3D) | 2.18
2022-08-08 | Boost Converter TPS61230ARNSR | Quantity: 3 | TPS61230A data sheet, product information and support | TI.com (https://www.ti.com/product/TPS61230A) | 1.974
2022-08-08 | Boost Converter ADP1614ACPZ-R7 | Quantity: 2 | ADP1614ACPZ-R7 Analog Devices | Mouser (https://www.mouser.com/ProductDetail/Analog-Devices/ADP1614ACPZ-R7) | 6.4
 |  |  | Total Cost | 18.674
 |  |  | Total Remaining | 212.116
44788 | TPS61235PRWLR (https://www.ti.com/product/TPS61235P/part-details/TPS61235PRWLR) | Quantity: 5 | TPS61235P data sheet, product information and support | TI.com (https://www.ti.com/product/TPS61235P?keyMatch=TPS61235P&tisearch=search-everything&usecase=GPN) | 3.77
 |  |  | Total Cost | 3.77
 |  |  | Total Remaining | 208.341
44802 | SI2369DS-T1-BE3 | Quantity: 4 | https://www.mouser.com/ProductDetail/Vishay-Siliconix/SI2369DS-T1-BE3?qs=CiayqK2gdcIOn%252BvoBWrtBg%3D%3D | 2.56
44802 | BQ25303J | Quantity: 4 | https://www.mouser.com/ProductDetail/Texas-Instruments/BQ25303JRTER?qs=DRkmTr78QARA1C7%2F12q3og%3D%3D | 8.72
 |  |  | Total Cost | 11.28
 |  |  | Total Remaining | 197.06
44802 | SI2333CDS-T1-GE3 | Quantity: 3 | https://www.digikey.com/en/products/detail/vishay-siliconix/SI2333CDS-T1-GE3/2441590 | 1.95
 |  |  | Total Cost | 1.95
 |  |  | Total Remaining | 195.11
2022-09-05 | Shopping list order | Qty: N/a | PCB Shopping List | 39.37
 |  |  | Total Remaining | 155.74
44818 | PCB | QTY:5 | JLCPCB | 40.11
 |  |  | Total Cost | 40.11
 |  |  | Total Remaining | 115.63
44819 | USB-C Port | Quantity: 4 | https://www.mouser.com/ProductDetail/GCT/USB4110-GF-A?qs=KUoIvG%2F9IlYiZvIXQjyJeA%3D%3D | 5.36
 |  |  | Total Cost | 5.36
 |  |  | Total Remaining | 110.27
44830 | USB-C Port | Quantity: 2 | https://www.mouser.com/ProductDetail/GCT/USB4110-GF-A?qs=KUoIvG%2F9IlYiZvIXQjyJeA%3D%3D | 2.68
44830 | USB-C Port | Quantity: 2 | https://www.digikey.com/en/products/detail/gct/USB4110-GF-A/10384547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 | 2.7
 |  |  | Total Cost | 5.38
 |  |  | Total Remaining | 104.89
44830 | 10nF capacitor | quantity: 5 | https://www.mouser.com/ProductDetail/TDK/C2012X5R2E103K125AA?qs=xLDY6iXSiQbVbz5hAOMqKw%3D%3D
 |  |  | Total Cost | 0.8
 |  |  | Total Remaining | 104.09
44854 | USB C to USB C | quantity : 1 | Amazon.com: 90 Degree Elbow Short USB C to USB C Cable 0.7FT,Typec USB3.1 Cable 20Gbps USB-C 3.2 Gen 2 Cable 4K Video Cord 100W PD Fast Charging Compatible,for Samsung T7/T5/X5 SSD,MacBook Pro,Mobile Hard Drive : Cell Phones & Accessories (https://www.amazon.com/Degree-Charging-Compatible-Samsung-MacBook/dp/B09LVNTC4F?rnid=23641588011&s=pc)
 |  |  | Total Cost | 10.9
 |  |  | Total Remaining | 93.19
Nov 11 2021 | Polar H9 Heatbeat sensor | quanity: 1 | https://www.amazon.com/POLAR-Heart-Rate-Sensor-Waterproof/dp/B08411DQ96?s=sporting-goods | 59.95
 |  |  | Total Cost | 59.95
 |  |  | Total Remaining | 33.24

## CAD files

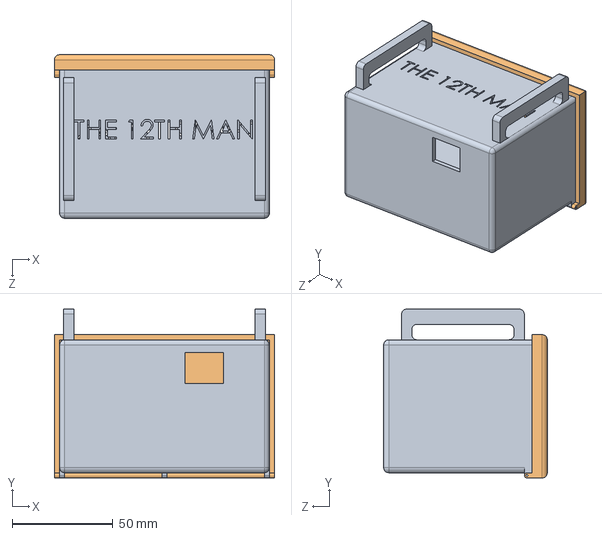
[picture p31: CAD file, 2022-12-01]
Micro Controller Subsystem/Assem1.SLDASM
109.2 x 83.8 x 81.3 mm
Updated 12th man prototpye
Part1^Assem1

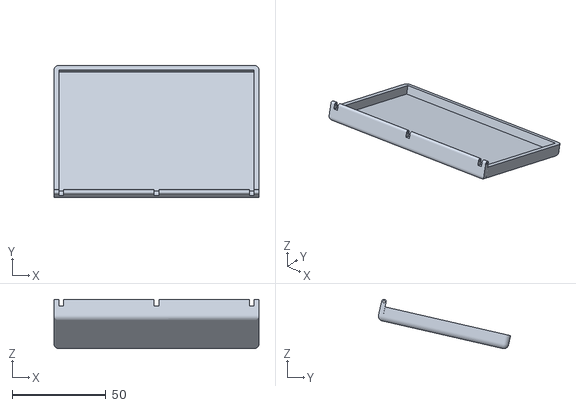
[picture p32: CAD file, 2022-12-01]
Micro Controller Subsystem/Assem1 - Part1^Assem1-1.STL
109.2 x 70.5 x 26.3

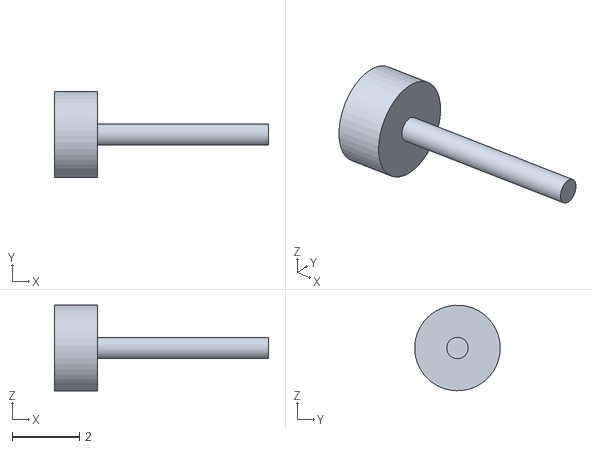
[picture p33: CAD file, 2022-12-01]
Micro Controller Subsystem/Assem1 - Part4^Assem1-1.STL
6.35 x 2.54 x 2.54

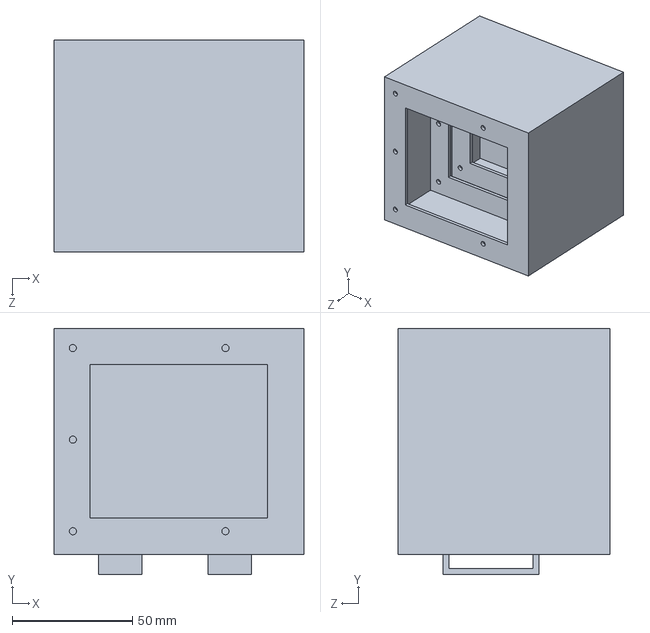
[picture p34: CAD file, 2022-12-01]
Micro Controller Subsystem/Josh Enclosure.SLDPRT
104.0 x 102.5 x 88.0 mm

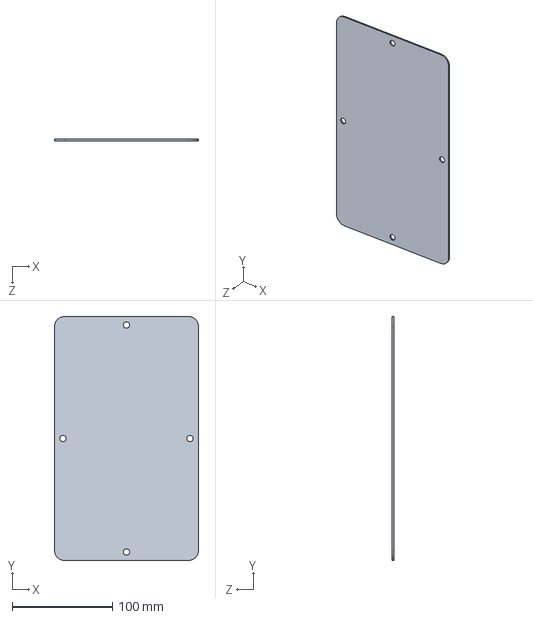
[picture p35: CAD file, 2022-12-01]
Micro Controller Subsystem/Part3.SLDPRT
144.0 x 244.0 x 1.50 mm

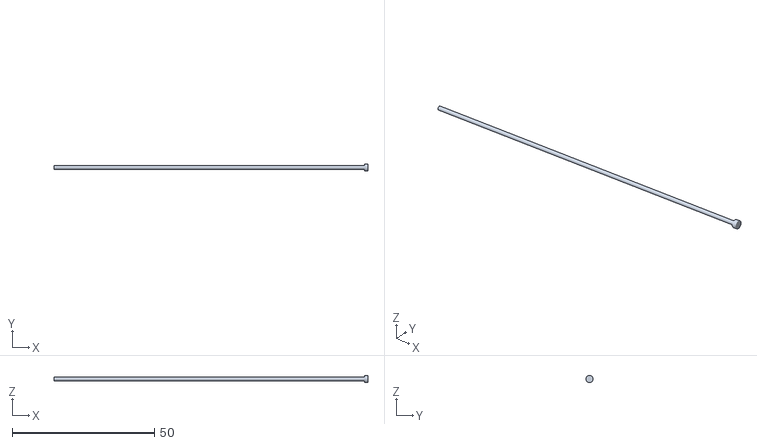
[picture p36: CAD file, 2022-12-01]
Micro Controller Subsystem/Assem1 - Part3^Assem1-1.STL
110.5 x 2.54 x 2.54

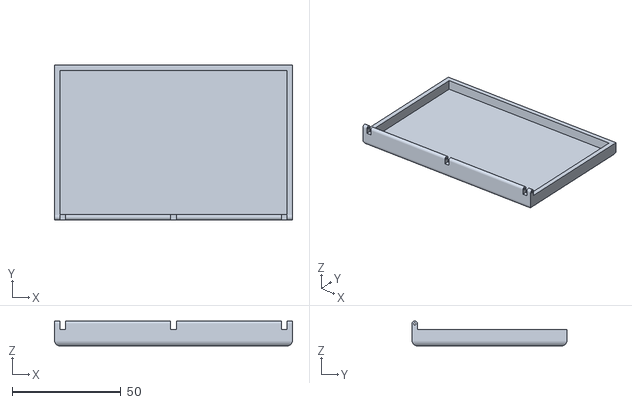
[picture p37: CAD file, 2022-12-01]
Micro Controller Subsystem/Assem1 - Part1^Assem1-1-1.STL
109.2 x 71.1 x 11.4

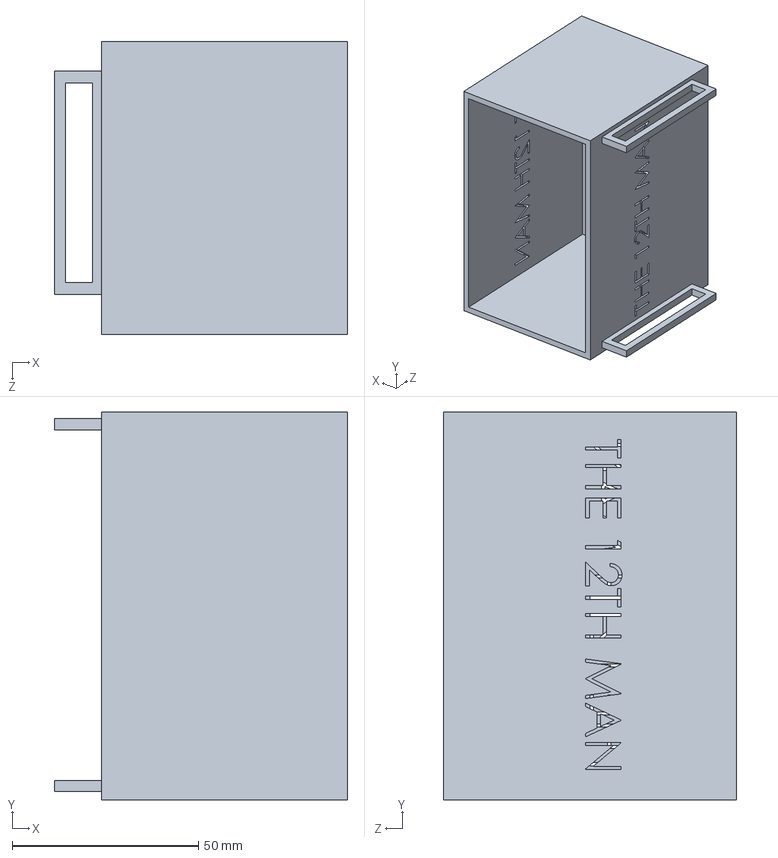
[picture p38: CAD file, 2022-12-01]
Micro Controller Subsystem/New Enclosure.SLDPRT
78.7 x 104.1 x 78.7 mm

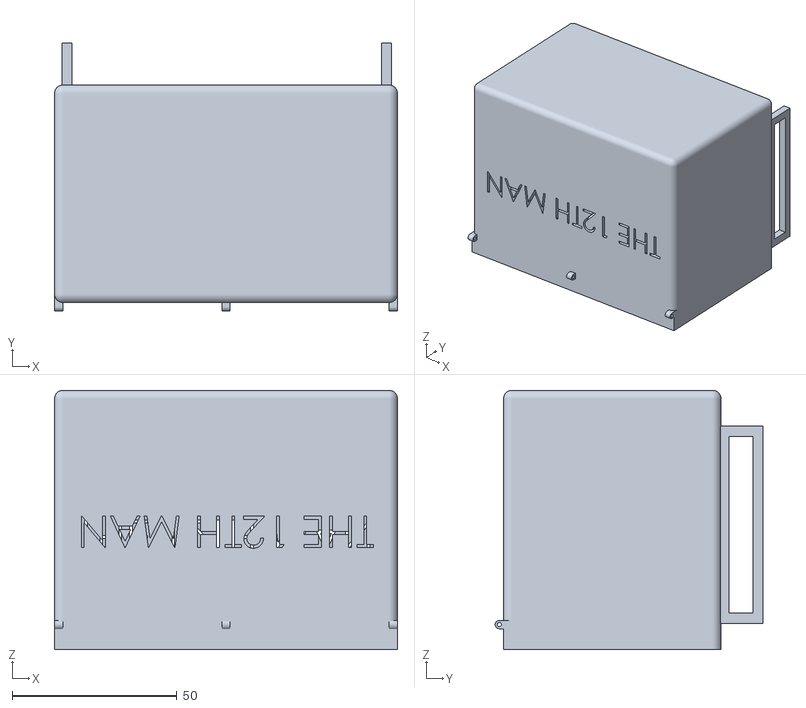
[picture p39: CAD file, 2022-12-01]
Micro Controller Subsystem/Assem1 - Updated 12th man prototpye-1.STL
104.1 x 81.3 x 78.7

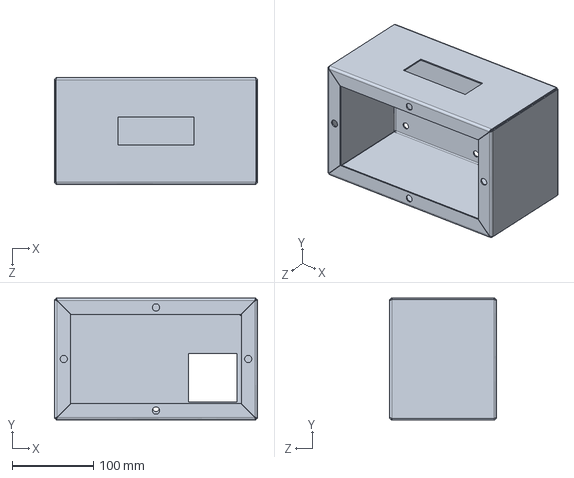
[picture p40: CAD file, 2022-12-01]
Micro Controller Subsystem/Part1.SLDPRT
250.0 x 150.0 x 131.5 mm

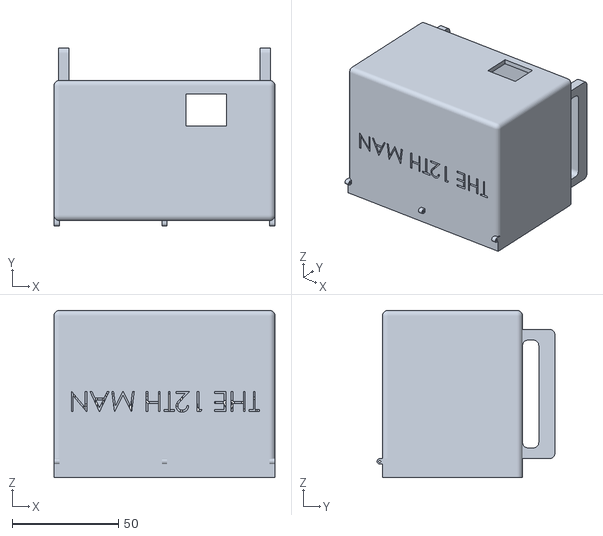
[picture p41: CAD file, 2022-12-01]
Micro Controller Subsystem/Assem1 - Updated 12th man prototpye-1-1.STL
104.1 x 83.8 x 78.7

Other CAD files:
Micro Controller Subsystem/Josh Enclosure format.STL
Micro Controller Subsystem/Updated 12th man prototpye.SLDPRT
Micro Controller Subsystem/Updated 12th man prototpye.STL

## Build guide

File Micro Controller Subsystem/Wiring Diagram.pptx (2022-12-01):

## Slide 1

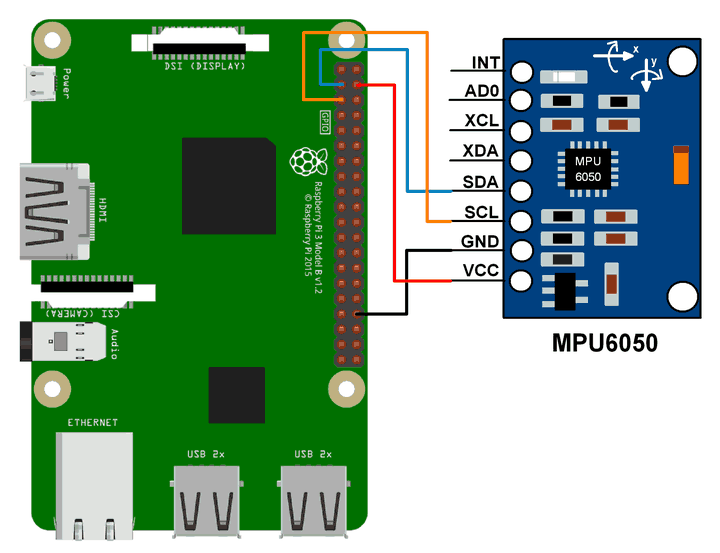
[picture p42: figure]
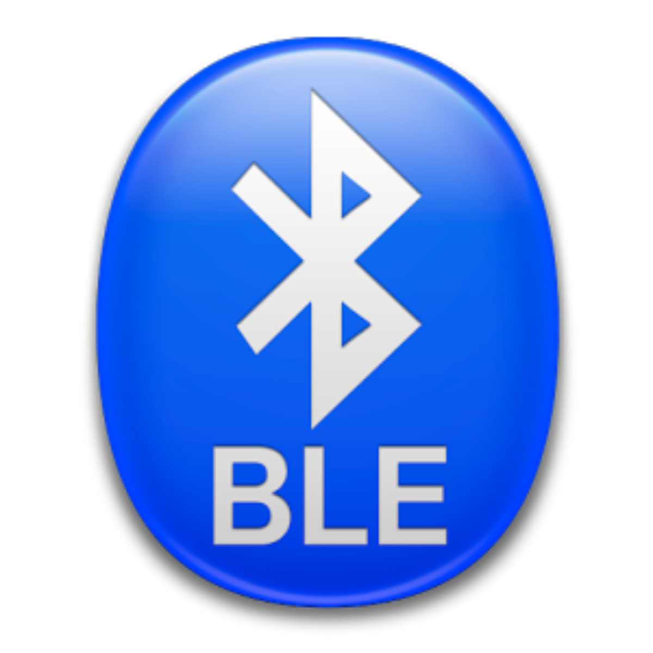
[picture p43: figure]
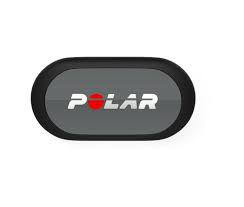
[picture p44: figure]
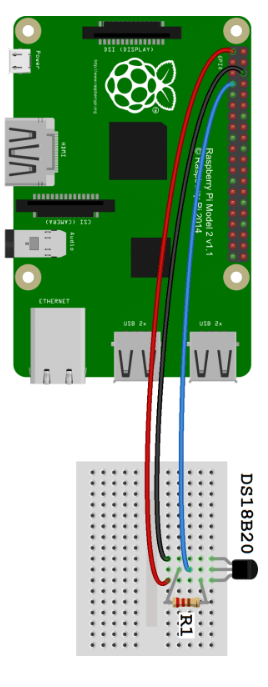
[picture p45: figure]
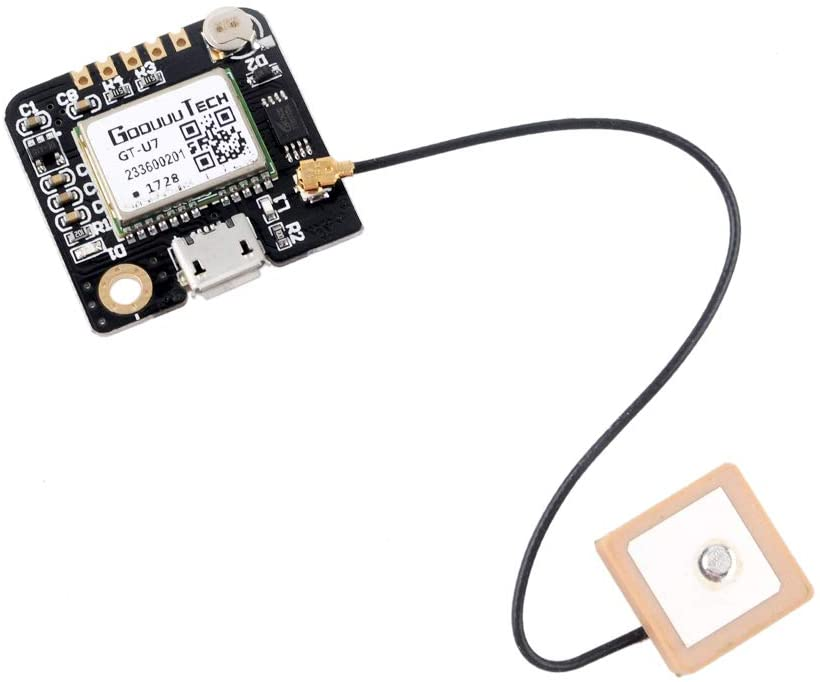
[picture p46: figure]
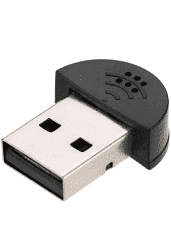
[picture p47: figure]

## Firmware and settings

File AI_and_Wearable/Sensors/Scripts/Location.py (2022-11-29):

#GPS Interfacing with Raspberry Pi using Pyhton
#http://www.electronicwings.com

import serial #import serial pacakge
import time #to be able to time delay
import sys  #import system package

def GPS_Info():
    global NMEA_buff #making global varibles so they can be accesed by all classes
    global lat_in_degrees
    global long_in_degrees
    nmea_time = [] 
    nmea_latitude = [] #create a list of latitude values
    nmea_longitude = [] #create a list of longitude values
    nmea_time = NMEA_buff[0] #extract time from GPGGA string
    nmea_latitude = NMEA_buff[1] #extract latitude from GPGGA string
    nmea_longitude = NMEA_buff[3]#extract longitude from GPGGA string
    
    try:
        lat = float(nmea_latitude) #converting string into float for calculation
        longi = float(nmea_longitude) #converting string into float for calculation
        lat_in_degrees = convert_to_degrees(lat)    #convert latitude into decimal format
        long_in_degrees = convert_to_degrees(longi) #convert longitude into decimal format
    except ValueError:
        lat_in_degrees = "30.628" #convert latitude into decimal format
        long_in_degrees = "96.334" #convert longitude into decimal format

#convert raw NMEA string into degree decimal format   
def convert_to_degrees(raw_value): #below is the conversion from NMEA to the commonly used terms of long and lat
    decimal_value = raw_value/100.00 
    degrees = int(decimal_value)
    mm_mmmm = (decimal_value - int(decimal_value))/0.6
    position = degrees + mm_mmmm
    position = "%.4f" %(position)
    return position
    


gpgga_info = "$GPGGA," #GPGGA is a basic GPS NMEA message
ser = serial.Serial ("/dev/serial0")              #Opening serial pot 0 where connection is established
GPGGA_buffer = 0
NMEA_buff = 0
lat_in_degrees = 0 #inital varible for lat
long_in_degrees = 0 #initial varible for longitude

#Open a specific file
file1 = open('/home/pi/ECEN404/Sensors/Data/location.txt', 'w'); #writing the data to GPSData.txt
                                  
good_header = "Latitude,Longitude,Time\n"; 
#writing the header to the file                                
file1.write(good_header);

tyme = time.perf_counter(); 

for i in range(10):
        received_data = (str)(ser.readline())
        GPGGA_data_available = received_data.find(gpgga_info)   #check for NMEA GPGGA string                 
        if (GPGGA_data_available>0): #check if there is data that is there
            GPGGA_buffer = received_data.split("$GPGGA,",1)[1]  #store data coming after "$GPGGA," string 
            NMEA_buff = (GPGGA_buffer.split(','))#store comma separated data in buffer
            GPS_Info()                                          #get time, latitude, longitude
 
            print("latitude:", lat_in_degrees," longitude: ", "-", long_in_degrees, '\n')
            file1.write(lat_in_degrees + "," + "-" + long_in_degrees + "," + str(time.perf_counter() - tyme) + "\n");
            time.sleep(3)
file1.close()

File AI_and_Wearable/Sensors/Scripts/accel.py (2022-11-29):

import smbus2 #I2C modules
import math #used for scaling calculations
import time #time delay imports

#Registers
reg_1 = 0x6b #MPU6050 power managment register
reg_2 = 0x6c #MPU6050 power managment register

def read_byte(reg): #reading the address
	return bus.read_byte_data(address, reg) 

def read_word(reg): #reading accelrometer data off MPU6050
	h = bus.read_byte_data(address, reg) #read the address for register
	l = bus.read_byte_data(address, reg+1) #read address from the next register
	value = (h << 8) + l #concentration of the higher and lower value for unsigned bit value
	return value #returned in 16 bit
#this function converts the 16 unsigned bit value
def read_word_2c(reg):
	val = read_word(reg) #read the 16 unsigned bit value
	if (val >= 0x8000): #if val is greater than register return
		return -((65535-val)+1) #gets signed value from mpu 6050
	else:
		return val
		
def dist(a, b): #calculating the magnitude
	return math.sqrt((a*a)+(b*b))
	
bus = smbus2.SMBus(1) # interface communication with the I2C bus
address = 0x68 #address of the MPU6050

#activate to be able to access the module through restting the sensor
bus.write_byte_data(address, reg_1, 0)

# Data collection portion for IMU
f = open("/home/pi/ECEN404/Sensors/Data/accel.txt", "w") #packet the data into a txt file
for i in range(50):#collect 100 values
	
	acceleration_xout = read_word_2c(0x3b) #collection of the x values from MPU6050 0x3b is the x register
	acceleration_yout = read_word_2c(0x3d) #collection of the y values from MPU6050 0x3b is the y register
	acceleration_zout = read_word_2c(0x3f) #collection of the z values from MPU6050 0x3b is the z register
	#the mpu6050 uses a sensitivity scale factor of 16384 LSB
	acceleration_xout_scaled = acceleration_xout / 16384.0 #scaling the x values
	acceleration_yout_scaled = acceleration_yout / 16384.0 #scaling the y values
	acceleration_zout_scaled = acceleration_zout / 16384.0 #scaling the z values
	
	f.write('{0} {1} {2}\n'.format(acceleration_xout_scaled, acceleration_yout_scaled, acceleration_zout_scaled))
	time.sleep(0.3)
	
f.close()

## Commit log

2022-12-01 Including Solid works Files, validations, wiring
    [Assem1 - Part1^Assem1-1-1.STL, Assem1 - Part1^Assem1-1.STL, Assem1 - Part3^Assem1-1.STL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]
2022-12-01 Include PCB Files
    PCB Files from Altium and simulations
    [Mosfet Voltages.xlsx, PCB Shopping List.xlsx, Shopping List (6) (1).xlsx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]
2022-12-01 Moved files to folder
    [Assem1 - Part1^Assem1-1-1.STL, Assem1 - Part1^Assem1-1.STL, Assem1 - Part3^Assem1-1.STL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]
